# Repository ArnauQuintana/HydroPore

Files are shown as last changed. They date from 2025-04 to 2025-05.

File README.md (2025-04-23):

# HydroPore
This project was realized in 2022 as my BSc thesis. 
The objective was to design and implement an embedded system for the control of a setup which looked like the following image:  

  

Where (1) are LVDT sensors for displacement measure, (2) a load cell for measuring pressure pushed by an actuator, (3) water pressure sensor and last but not least, 4 cameras in each side of the experiment, like this: 



My mission was to control the actuator while getting data from all sensors. I designed and implemented the PCB with all conditioning and required circuits for this application.  
Here is a photo of the final solution:  



## 📁 Project 1 - [HydroPore_FW]

**Description:**  
Implementation of the bare-metal firmware in a MSP430 microcontroller from TI.

**Key Features:**
- All code was developed for a MSP430 from TI. 
- It is not a real-time application, so no time requirements were needed to be met. 
- It receives and sends data with a GUI in Python through UART protocol

**Location:** `/HydroPore_FW/`

---

## 📁 Project 2 - [HydroPore_Cameras]

**Description:**  
This project was intended to control 1 serial camera with Arduino (we had a total of 4 cameras, so 4 arduinos). Its objective was to trigger the camera capture, read the image information and save it in an SD card every time the main uController asked to. 

**Key Features:**
- Received triggers from central control card with normal GPIOs.
- Protocol used for sending image information from Arduino to SD shell was SPI. 

**Location:** `/HydroPore_Cameras/`

---

## 📁 Project 3 - [HydroPore_GUI]

**Description:**  
Simple Python GUI using 'tkinter' for sending commands and receiving data from sensors. 

**Key Features:**
- Serial communication with UART
- It generates a 'RESULTS.txt' file with data from sensors.

**Location:** `/HydroPore_GUI/`

---

## 📁 Project 4 - [PCB_Project_HydroPore]

**Description:**  
This is the PCB where all conditioning circuits and the microcontroller are allocated. 

**Key Features:**
- Supplied by 2 sources, one for the power part (actuator) and one for the conditioning of sensors data. 
- UART communication for exchanging data with GUI in Python. 

**Location:** `/PCB_Project_HydroPore/`

---
## 📌 Additional Notes

- It is important to consider that this was my first 'big' project. It was entirely realized in 6 months, the short experience and short deadline may made me do some parts not as optimal as possible or containing bugs and innacuraccies. 
- Each project includes its own detailed `README.md` file inside its folder.

---

## 📄 License

This repository is licensed under the [MIT License]. Please see the `LICENSE` file for more details.

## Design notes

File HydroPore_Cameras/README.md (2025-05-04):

# HydroPore Cameras

- Cameras looked like:
  


- PCB built to allocate the camera, the arduino and the SD card shield:
  


- Schematic of the PCB:



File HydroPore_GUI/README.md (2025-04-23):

# HydroPore_GUI
The project was developed with Jupyter Notebook.
The GUI was a simple screen with buttons to move around the menus and reach the command needed.

## Main Menu:


## Commands available:


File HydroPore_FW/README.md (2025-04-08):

# HydroPore_FW

ANEXO_6

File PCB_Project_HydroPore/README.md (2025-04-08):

# PCB_Project_HydroPore

  



Top layer:


Bottom Layer:



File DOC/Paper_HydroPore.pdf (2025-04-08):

# Design and implementation of ‘HydroPore’ Electronic System

Arnau Quintana Llorens
Electronics Telecommunication Engineering University of Barcelona, UB Barcelona, Spain

Abstract—This document summarizes a Final Grade’s Project whose objective is to develop all the electronics that will control an experimental setup. This project includes PCB design, coding and development of a user interface.

Keywords—PCB; C Coding; Python; Arduino; Experimental setup; Electronics; LVDT; Load Cell.

I. INTRODUCTION
The experimental setup consists of an extern structure that will support an internal construction. The internal is formed by a base with a rock at the top and, just above, there’s another structure with another rock that fits perfectly with the first one. Above the second structure we can find death weight that will apply a vertically force. The objective is to move 10 mm the lower structure forcing the two rocks to rub each other. Before the start of the movement, the system will be saturated of water and during the experiment we need to measure:
- Horizontal displacement of the lower structure.
- Vertical displacement of the higher structure.
- Water pressure difference.
- Water removed from the system thought the holes on the 4 laterals.
- Applied force vertically with death weight.
- Applied force horizontally to move the base.

Our objectives can be divided into 4 subobjectives:

1. Study the problem and propose a solution to the manager.
2. Design and implementation of the PCB that will control the system.
3. Develop the software that will manage the PCB.
4. Develop an interface to make the control of the system user friendly.

II. MATERIALS AND METHODS

A. Materials
- LVDT [1]: to measure vertical and horizontal displacement. They are located in position marked with number 1 on Fig 1.
- Load cell [2]: to measure vertical and horizontal applied force. They are located in position marked with number 2 on Fig 1.
- Water pressure sensor [3]: to measure changes of pressure between movements. It is located in position marked with letter ‘Q’ on Fig 1.
- Ultrasonic sensor [4]: to have a security limit of the movement. Will be located at the end of the movement range of the structure.
- Serial cameras [5]: to know how much water has been removed from the system. Will be one of them on every side of the structure.
- Actuator [6]: to move the structure. It is located in position marked with ‘σT’ on Fig 1.

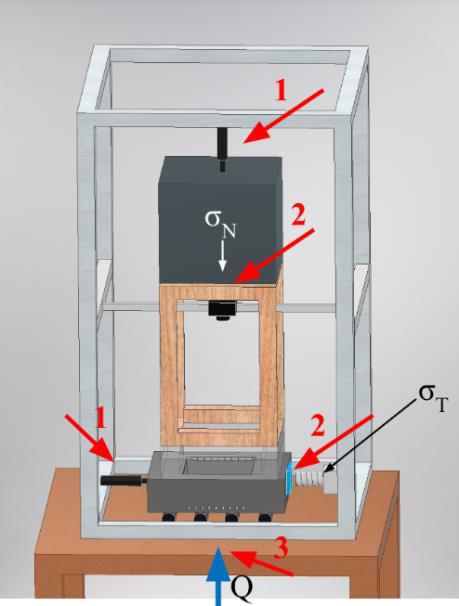
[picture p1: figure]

Fig 1. ‘HydroPore’ experimental setup.

B. Methods
We have divided the design of the system in 4 layers:
- Physical layer: includes all the transducers and the mechanicals.
- Electronics layer includes the PCB and all the components.
- Control layer: includes the software of the microcontroller and the Arduino.
- User layer: includes the methods that the user has to interact with the system.

A layer design helps us to correct the course of any decision during the development of the project without changing a lot of aspects. Physical and electronics layer are palpable; control and user layers are logic.

We have designed the system going from the physical layer to user layer.

III. RESULTS
The initial propose to the head of the project has been approved and developed.

Hardware designed meets the expectations. It is capable of collect all transducers data, process it and export to a PC via UART.

PCB is designed according to EN 55011:2016 norm about electromagnetic emissions on a scientific equipment. In Fig 2 we can see the results.

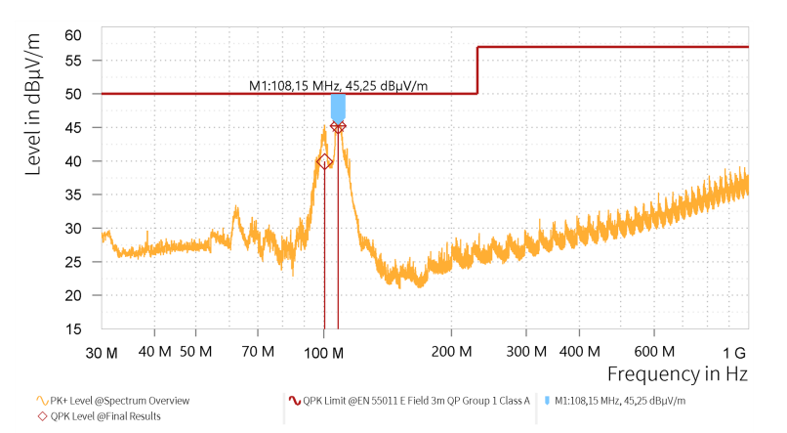
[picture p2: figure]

Fig 2. Results of radiated emissions according to EN-55011.
The software can monitor all the system and detect errors.

User interface can send commands to interact with the system and get data from it with a user-friendly format.

IV. DISCUSSION
After all the explanations of the heads of the project, we traced a solution to meet the requirements.

The PCB is a four-layer design, all of them dedicated to signals. The equipment is placed in a methacrylate cage, to avoid having current circulating through a metal case.

We have tested radiated emissions in a semi-anechoic chamber as we see in Fig 3.

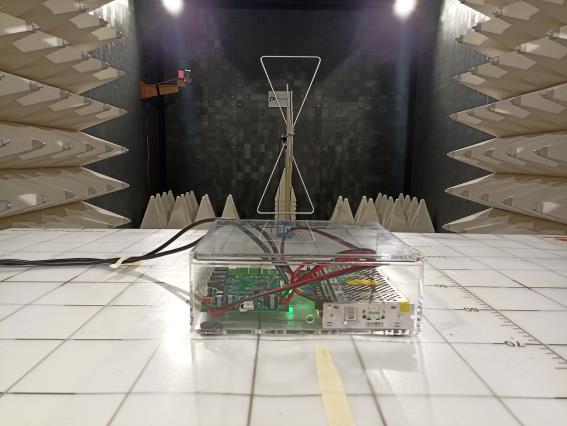
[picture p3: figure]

Fig 3. EUT in the semi-anechoic chamber.

Developed software can control all the electronics and can collect of transducers data, process it and send it to PC via UART.

The user interface is based on an application that have different buttons assigned to all commands that we can send to PCB, as we see in Fig 4.

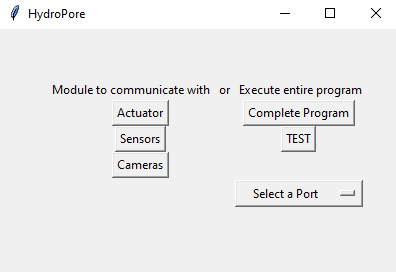
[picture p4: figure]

Fig 4. Main window of the user interface.

REFERENCES

[1] TE Connectivity. (2017, Jul.). DC-SE Series, General Purpose DC LVDT
[Online]. | | | | Available | | on:
https://www.te.com/commerce/DocumentDelivery/DDEController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
[2] HBM. (2021, Jan. 26). S2M Force Transducer Datasheet [Online].
Available | | | | | | on:
https://www.hbm.com/fileadmin/mediapool/hbmdoc/technical/B03594.p df
[3] Sensata Technologies. (2021. Jun. 18). IPS Series Industrial Pressure
Transducer | [Online]. | Available | on: | https://docs.rs-
online.com/165e/A700000008782550.pdf
[4] Kitronik. (2021, Jan. 28). Ultrasoni Ranging Module HC-SR04 [Online]. Disponible en: https://docs.rs-online.com/8bc5/A700000007388293.pdf
[5] Adafruit Industries. (2016, Jun.12). PTC06 Serial Camera Specification
[Online]. | | | Available | on: | | https://docs.rs-
online.com/bb24/0900766b81533f88.pdf
[6] Actuonix Motion Devices Inc. (2016, Sept). Miniature Linear Motion
Series | · | P16 | [Online]. | Available | on: | https://docs.rs-
online.com/1cf0/0900766b81682dc9.pdf

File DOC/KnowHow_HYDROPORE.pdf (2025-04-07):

Versión 0

‘Know How’ del montaje experimental ‘HydroPore’

# ‘KNOW HOW’ DEL MONTAJE EXPERIMENTAL ‘HYDROPORE’

Autor: Arnau Quintana Llorens

El presente documento pretende explicar el funcionamiento de cada una de las partes del sistema, tanto a nivel de circuito, el código y los sensores.

## CONTROL DE CAMBIOS

Autor | Apartado | Fecha | Versión
Arnau Quintana | TODOS | 18-09-2022 | 0

## ÍNDICE

## PCB

En este apartado se puede encontrar la explicación de todos los circuitos que forman el PCB.

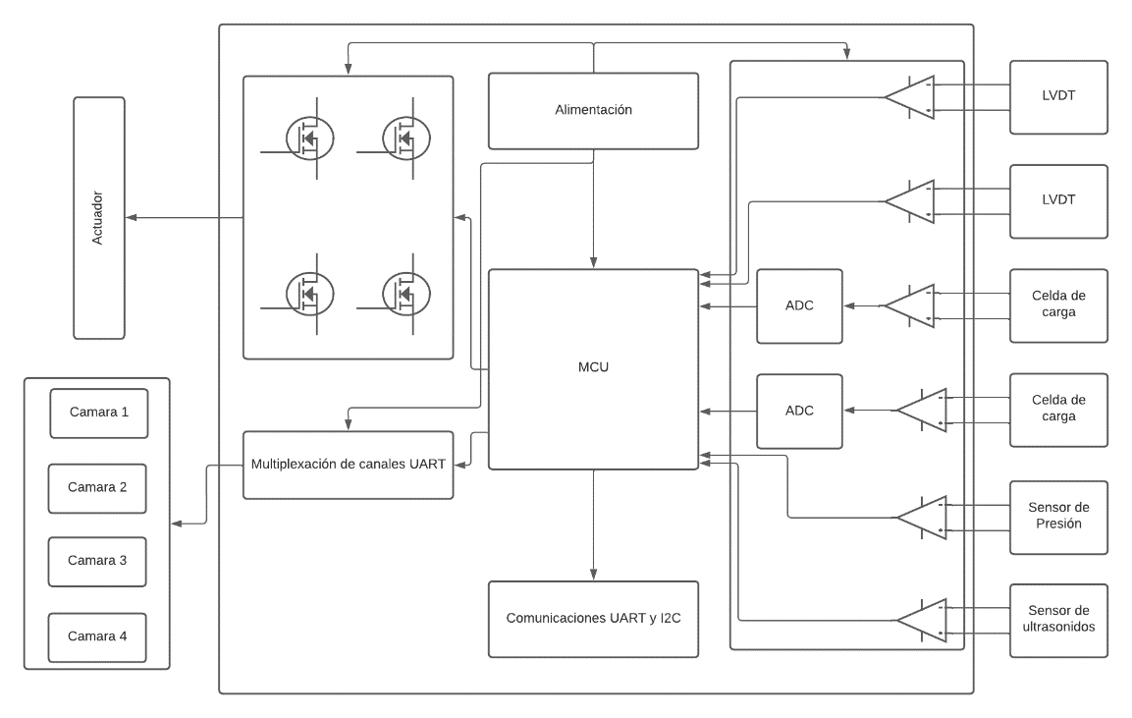
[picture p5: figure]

LOAD CELLS
Las celdas elegidas para el proyecto disponen de 6 cables: Data+, Data-, Alimentación+, Alimentación-, Sensado de alimentación + y sensado de alimentación -.

El circuito para poder recoger datos de las celdas se compone básicamente de 2 partes: un amplificador de instrumentación y un ADC de 14 bits.

El amplificador de instrumentación nos ayuda a amplificar la señal y rechazar el modo común, que en este contexto es muy crítico al trabajar con señales tan pequeñas. Usamos un ADC externo porque el microcontrolador dispone de uno interno de 12 bits, el cual se no queda un poco corto para las señales que medimos de este sensor.

El amplificador tiene una ganancia fija de 160, es decir, la señal que entra saldrá amplificada 160 veces. El ADC dispone de 14 bits, es decir, de hasta 16384 valores digitales. Como lo alimentamos a 5V significa que por cada voltio disponemos de 3276 valores aproximadamente. Esto significa que 1V a la entrada del ADC, se traduce en un valor digital de 3276 a la salida. El cambio es lineal, es decir, siempre que añadamos peso, la salida cambiará de manera proporcional.

Nuestro rango medible es de 0N a 300N. Si quisiéramos aumentarlo, por ejemplo, hasta 600N, deberíamos, como mínimo, cambiar el amplificador y poner uno de ganancia fija menor; existe un modelo igual que en lugar de 160 de ganancia, tiene 80 (AD8293G80ARJZ-R7). El amplificador se alimenta a 5V, si intentamos sacar más de esa tensión, el componente se satura y a su salida veremos 5V por mucho que aumentemos por encima de 300N la fuerza aplicada en la celda.

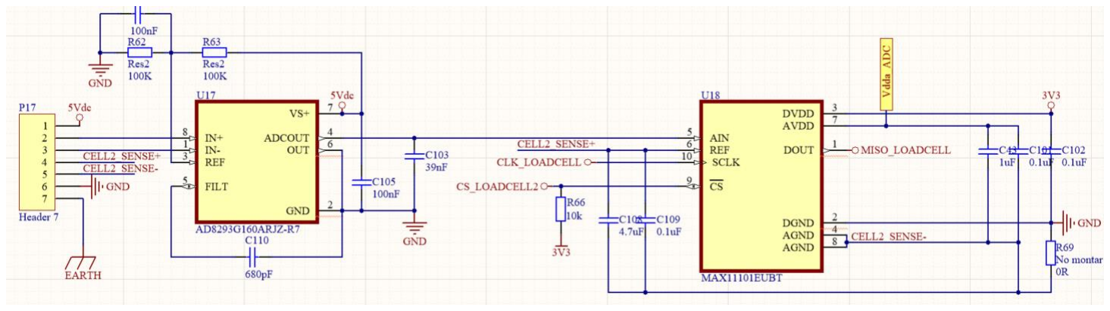
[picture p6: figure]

LVDTs
Este sensor dispone de 4 líneas: +15Vdc, GND, Datos+ y Datos-. Nos devuelve una señal de 0V a 5V dependiendo de la extensión del núcleo. Nuestro sensor es 3.3V tolerante, por lo que aparte de acondicionar la señal analógica debemos reducir su amplitud. Para ello usamos un amplificador diferencial, que básicamente es un amplificador operacional con una cierta topología capaz de amplificar la diferencia entre sus entradas. Si en la entrada positiva tenemos 6V y en la otra 1V, la salida será de 5V, siempre y cuando no la amplifiquemos jugando con el valor de las resistencias. Nosotros hemos dimensionado el circuito teniendo en cuenta que la señal máxima que nos puede devolver el LVDT es de 6V (haciendo pruebas en el laboratorio vimos que esa era la tolerancia), por lo que cuando el LVDT devuelva 6V, el microcontrolador recibirá 3.3V.

Vo = (

R65
R83

) · (VPIN2 − VPIN3)

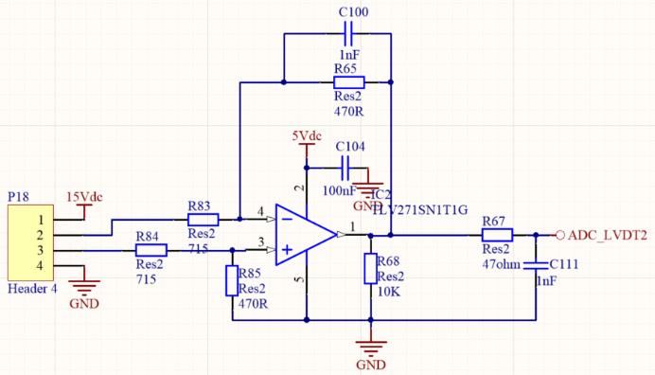
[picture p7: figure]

SENSOR DE PRESIÓN
Este sensor es muy parecido en cuanto a funcionamiento al LVDT. Se alimenta a 15V y nos devuelve una señal de 0V a 5V dependiendo de la presión leída. Usamos el mismo circuito que en los LVDT para acondicionar la señal.

ULTRASONIDOS
Lo único que hemos tenido que añadir ha sido un pequeño divisor resistivo, ya que el sensor nos devuelve una señal digital de 0V a 5V, mientras que nuestro microcontrolador soporta de 0V a 3.3V. Este sensor sólo tiene parte digital, por lo que no hemos tenido que acondicionar nada.

CÁMARAS
En el PCB tenemos un circuito dedicado a la comunicación con las cámaras, pero parte de él no lo usamos por cuestiones de eficiencia. Lo compone 2 partes: un multiplexor digital y un driver RS232. El primero nos permite usar 2 canales UART para transformarlos en 4, tal como muestra la siguiente imagen:

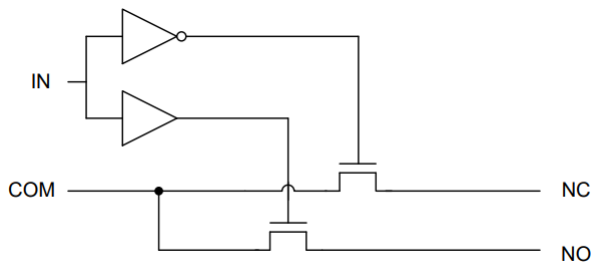
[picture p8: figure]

IN es el selector de canal, COM es la señal que queremos multiplexar, NC y NO son las dos salidas. Es un circuito bidireccional, por lo que podemos ir de COM a NC o NO, o podemos ir de NC o NO a COM; esto nos permite tanto enviar datos como recibirlos a través de la misma línea.

El driver RS232 nos ayuda a pasar la señal de niveles UART a niveles RS232, el cual es más seguro para comunicaciones en las que haya cierta distancia.

Los puentes de la parte inferior de la imagen son los que usamos en nuestro circuito final, ya que sirven para poder saltar el driver RS232.

En el montaje final únicamente se usa el multiplexor digital y los puentes para saltar el driver RS232 como comentamos. Esto es así porque no nos comunicamos a través de UART con las cámaras ya que cada una de ellas tiene un Arduino dedicado. Las líneas que van a las cámaras son la de ‘trigger’ y la de ‘acknowledge’ del ‘trigger’.

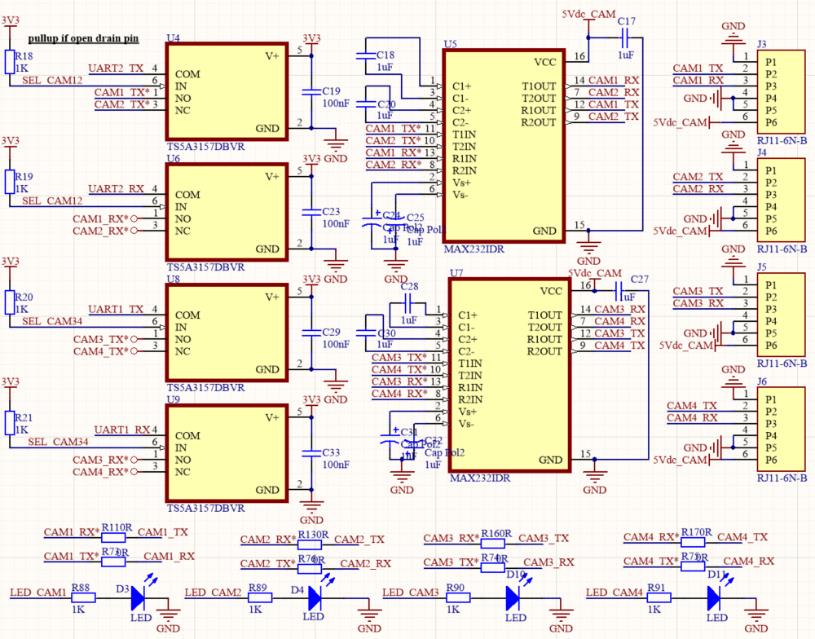
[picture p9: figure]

La solución final para tomar las imágenes con las cámaras es la siguiente:

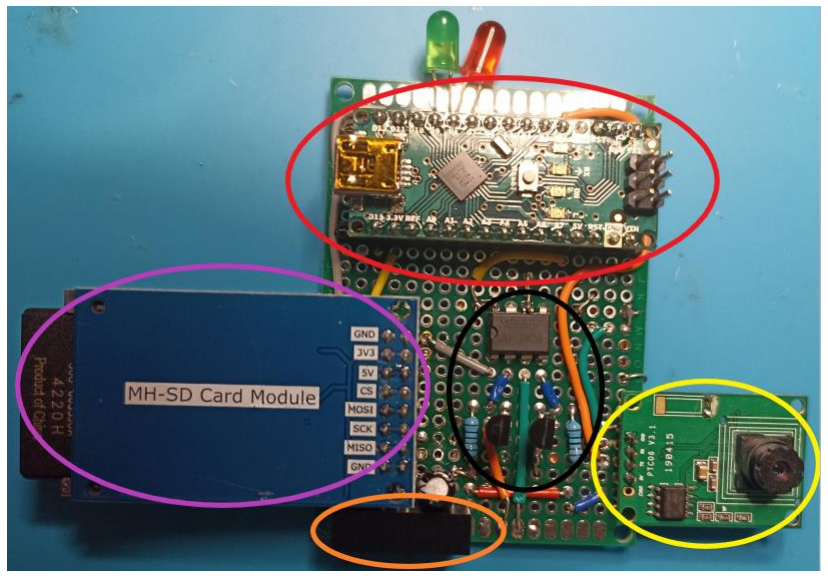
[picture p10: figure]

COLOR | PARTE DEL SISTEMA
| Arduino
| Circuito ‘toggle’ ON/OFF
| ‘Shield’ tarjeta SD
| Convertidor DCDC aislado 15V a 5V
| Cámara serie

Alimentamos el módulo con el convertidor DCDC MPF1505S-1W, que le entran 15V desde la PCB principal a través del cable y los reduce a 5V, que es la tensión con la que funciona todos los componentes del módulo.

En esta PCB se sitúa: el ‘SHIELD’ donde se conecta la tarjeta SD en la que guardaremos las imágenes, la cámara que toma las imágenes, el Arduino que controla la faena, un convertidor que alimenta toda la placa y un pequeño circuito para detectar el ‘trigger’ que nos envía el microcontrolador principal para saber cuándo debemos empezar o parar de tomar imágenes, ya que una vez empezamos, cada 20 segundos aproximadamente se tomará una imagen.

Existe una cuestión muy importante a tener en cuenta en este circuito: la referencia de la parte del Arduino y la referencia del microcontrolador principal no son la misma, ya que usamos un DCDC aislado para alimentar todo el módulo. Debemos separar el ‘trigger’ que enviamos desde el microcontrolador principal al Arduino y la señal de ‘trigger correcto’ que envía el Arduino al microcontrolador principal. Para esta misión hemos usado optoacopladores, son dispositivos dedicados específicamente a lo que necesitamos.

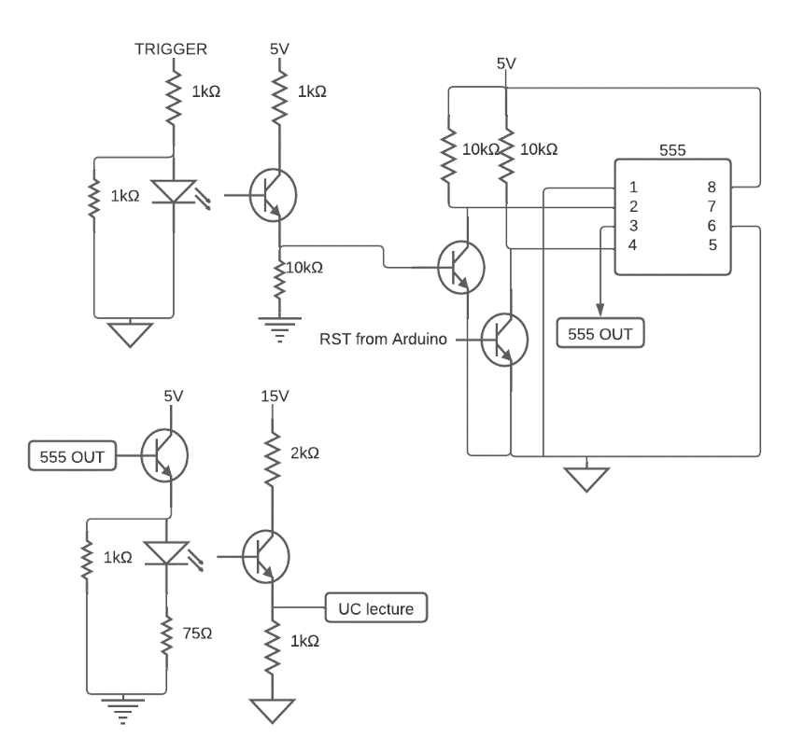
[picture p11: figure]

Las siguientes tablas resumen las conexiones entre la cámara, la tarjeta SD y el Arduino:

Pin Arduino | Pin adaptador tarjeta SD
GND | GND
3.3V | 3V3*
5V | 5V*
D10 | CS
D11 | MOSI
D13 | SCK
D12 | MISO
GND | GND
*Si conectamos 5V, no conectamos 3V3. Si conectamos 3V3, no conectamos 5V.
Pin Arduino | Pin Cámara
GND | GND
D3 | RX (divisor resistivo 5V a 3V3)
D2 | TX
5V | 5V
Pin Arduino | Circuito 555
D5 | 555 OUT
D6 | RST from Arduino
Cable RJ11 | Módulo Cámaras
Cable rojo | TRIGGER
Cable negro | UC lecture
Cable blanco | 15V
Cable gris | GND

ACTUADOR

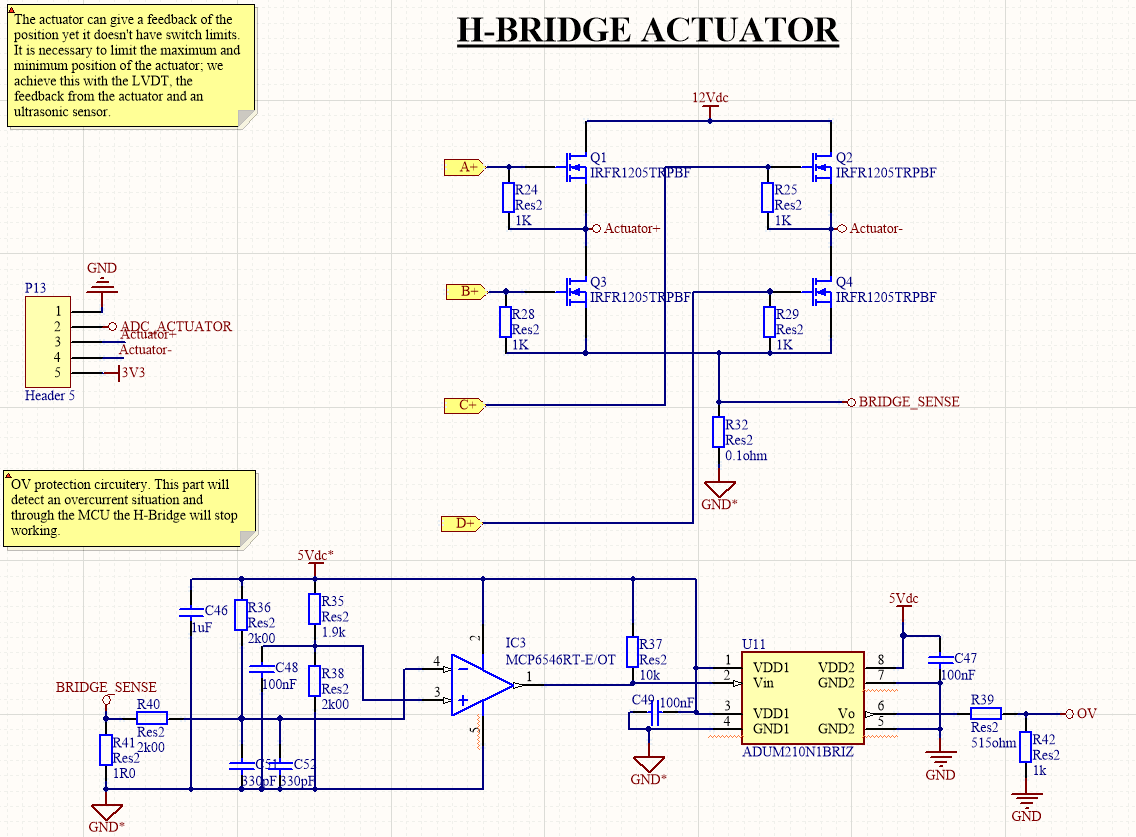
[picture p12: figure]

En esta primera imagen vemos el puente H con el circuito detector de sobre corriente. El actuador se moverá hacia adelante o hacia atrás dependiendo de cómo lo polaricemos. La manera más sencilla y efectiva de usar esa capacidad es con un puente en H, si cerramos los transistores en diagonal haremos fluir la corriente a través de la carga, que es el actuador, en la dirección que nos interese.

Por otro lado, tenemos el circuito de la parte inferior de la imagen. Mediante una SHUNT (una resistencia de baja impedancia y tolerancia) sensaremos la corriente que atraviesa el puente para poder proteger a los transistores de un cortocircuito o de un consumo excesivo. Se basa en la ley de ohm, por ejemplo, si la corriente que atraviesa la SHUNT es de 1A y la resistencia de es 1mOhm, la señal ‘BridgeSense’ será de 1mV (V = I · R). Lo que hacemos con esa señal es llevarla directamente a la entrada negativa de un comparador. En la entrada positiva tenemos un nivel de continua constante. Si la señal de la SHUNT no supera esa señal de continua, todo va bien, la salida será 1 y no tendremos que hacer nada. En cuando la salida sea 0, deberemos actuar para parar el movimiento del actuador, ya que algo no está funcionando como debería.

En la segunda imagen, que encontramos más abajo, tenemos los drivers de los transistores. Estos se dedican a adaptar la señal del microcontrolador a una que sea correcta para la puerta de los MOS, ya que son muy delicados. Además, esos drivers son aislados, lo que significa que la referencia de la parte izquierda y la de la derecha no son iguales. Alimentamos el puente H con la fuente de 12V y el microcontrolador se alimenta indirectamente de la fuente de 15V, sus referencias son distintas y hemos de tenerlo en cuenta. Los componentes que rodean al driver son: un filtro RC en la entrada (para eliminar componentes de alta frecuencia de la señal), capacidades de desacoplo en ambos lados del driver (para mantener estable la tensión de alimentación), una resistencia de puerta (para limitar la corriente que llega a la gate del MOSFET y una resistencia y un diodo de descarga de la puerta (para descargar la carga de la puerta mucho más rápido cuando debamos abrir el transistor).

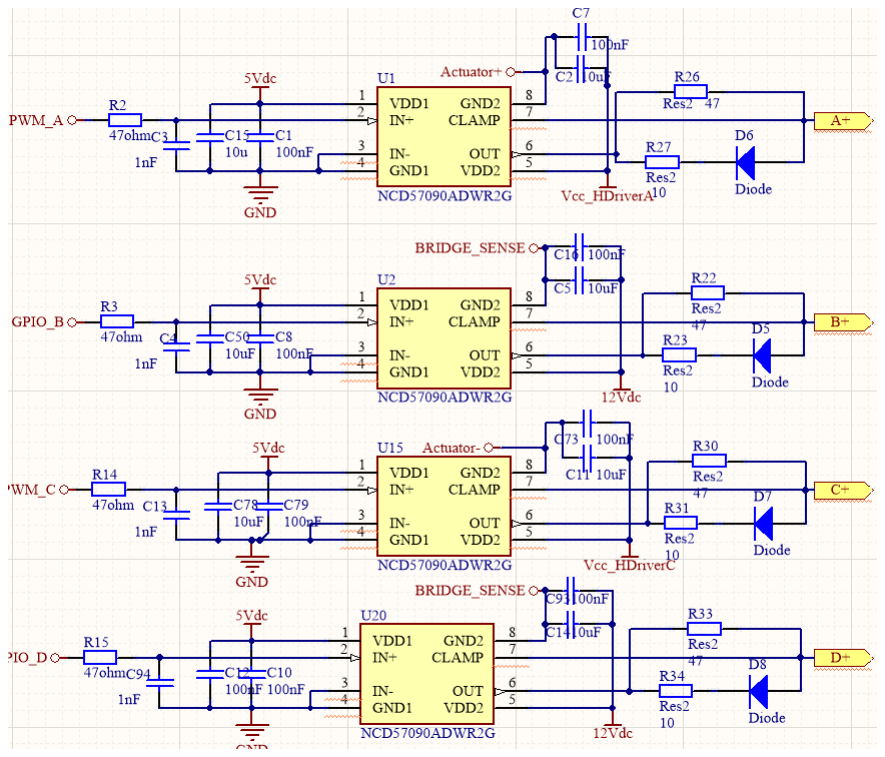
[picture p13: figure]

ALIMENTACIONES
Todas las tensiones que obtienen a partir de 2 fuentes, una de 12V para la parte del puente H, otra de 15V para toda la parte de control y sensores. Para obtener todas las alimentaciones que necesitamos, ya que, por ejemplo, el microcontrolador necesita 3.3V y algunos sensores 5V, usamos LDOs (reguladores lineales). Más abajo tenemos una imagen del circuito, todos son parecidos: condensadores en la entrada y salida para mantener estable la tensión y reducir el rizado.

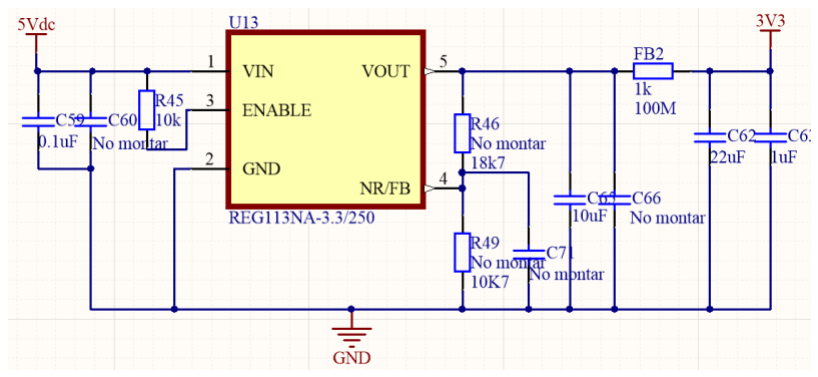
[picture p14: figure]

POSICIÓN DE LOS CIRCUITOS EN EL PCB

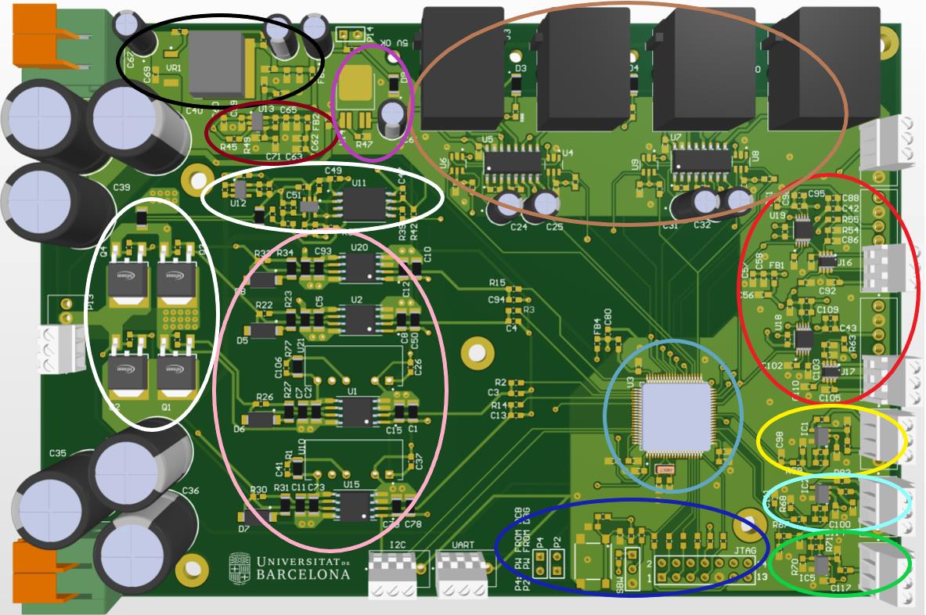
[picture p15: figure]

COLOR | PARTE DEL SISTEMA
| LDO 15Vdc a 5Vdc para sensores, drivers del puente H y uControlador
| LDO 5Vdc a 3.3Vdc para el uControlador
| Regulador lineal de 15Vdc a 5Vdc para Arduinos y cámaras
| Driver a RS232 y multiplexores digitales para las cámaras
| Puente H y circuito de detección de sobre corriente
| Drivers del puente H
| Conector de programación del uControlador
| uControlador
| Acondicionamiento de la señal del sensor de presión
| Acondicionamiento de la señal del LVDT1
| Acondicionamiento de la señal del LVDT2
| Acondicionamiento de la señal de las celdas de carga

ERRORES EN PCB
Este apartado pretende resumir los errores de diseño que se han cometido y que deberían corregirse de cara a una versión B de la PCB.
- Referencia de los convertidores de los drivers del ‘high side’ del puente H.

La referencia del secundario del convertidor que alimenta el driver del transistor ‘A’ debe ir conectada a la ‘net’ ‘Actuator+’, puesto que es esta la que está conectada al ‘source’ del transistor.

La referencia del secundario del convertidor que alimenta el driver del transistor ‘C’, debe ir conectada a la ‘net’ ‘Actuator-‘, puesto que es esta la que va conectada al ‘source’ del transistor.

Para arreglar este problema en la versión A del PCB, se ha cortado la pista que une GND con la referencia de la parte del secundario del convertidor y se ha unido la referencia del convertidor a donde corresponde con un cable.

- Pin ‘OUT’ del amplificador de instrumentación cortocircuitado con GND.

Al realizar el esquema y pasar una línea por encima de la otra, el pin ‘OUT’ se cortocircuitó con la GND. El pin ‘OUT’ debe ir conectado al condensador que tiene el otro pin conectado a ‘FILT’. En caso de duda, en el datasheet del componente aparece un esquema de cómo debe ir conectado el amplificador.

Para corregir el error en la versión A del PCB, se ha levantado el pin ‘OUT’ del driver para que no toque con el pad y se ha levantado el condensador que debe unir ‘OUT’ y ‘FILT’ para que tampoco toque con GND. Mediante un cable se ha unido el pin del driver con el condensador.

- LDO de la alimentación de las cámaras y Arduino no usado.

La primera idea del proyecto para la parte de las cámaras es que se comunicaran con el microcontrolador principal, por lo que únicamente deberíamos hacer llegar los 5V a las cámaras. Conforme avanzaba el proyecto y nos dimos cuenta de lo poco eficiente que era ese método, ingeniamos un módulo para poder resolver el problema, pero ese módulo consumía mucho más que la cámara sola. Al realizar las pruebas funciones del PCB nos dimos cuenta de que usar un LDO para alimentar los 4 módulos no era viable, ya que el consumo de cada uno de ellos es de aproximadamente 1.5W, lo que hacía calentarse en exceso al regulador.

Para solucionar el problema en la versión A de circuito hemos cortocircuitado los 5V de las cámaras con los 15V de la fuente, es decir, hemos quitado todos los componentes de la parte de alimentación de las cámaras y hemos cortocircuitado la entrada y la salida del regulador. Esto hace que la línea 5Vdc_CAM, sea en realidad, 15V. Esos 15V luego los pasamos a 5V en cada módulo con un convertidor DCDC (podemos revisar la explicación de cómo funciona el módulo un poco más arriba, en este mismo documento).

- Serigrafia en PCB y pines del ultrasonidos.

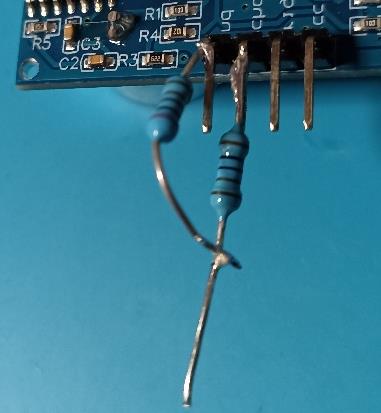
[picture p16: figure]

En la capa bottom del PCB tenemos el nombre de cada pin para poderlos identificar. Por motivos de software, los pines ECHO y TRIGGER están girados, es decir, donde en la placa pone ‘trigger’ conectamos el ‘echo’ y donde pone ‘echo’ conectamos el ‘tigger’.

Además, hemos incorporado un divisor de tensión en el pin ‘ECHO’ del ultrasonidos tal como vemos en la imagen. Esa señal es de 5V mientras que el micro permite 3.3V.

## CÓDIGO EN C

Usamos un MSP430 de Texas Instruments, concretamente el MSP430FR6043. Para programarlo, usamos el Code Composer Studio, la versión 10.4.0. El programador es el MSP-FET430UIF V1.

Tenemos el código separado por archivos intentando tener en cada uno funciones relacionadas entre sí.

Main.c | Archivo principal. El micro ejecuta la función ‘main’ situada en este archivo.
ADC.c | Funciones relacionadas con el ADC, desde configuración hasta recogida de datos.
ADC.h | Header del ADC.c. Encontramos las funciones que usamos en otra parte del código.
Control.c | Funciones principales, en este archivo usamos todas las librerías.
Control.h | Header del Control.c.
COMs.c | Funciones relacionadas con las comunicaciones UART y SPI.
COMs.h | Header de las funciones del archivo COM.c.
Clocks.c | Contiene la función de inicialización de los relojes.
Clocks.h | Header de la función de inicialización de los relojes.
DrivingH.c | Funciones relacionadas con el ultrasonidos y el movimiento del actuador.
DrivingH.h | Header con las funciones del archivo DrivingH.c.

En el código se han dejado comentada una parte del código, es decir, en la última ‘release’ del código no se incluye, su función es la siguiente: si el microcontrolador detecta medidas muy bajas en el LVDT (rondando los 0.01mm) que lo dé como error y no mueva el actuador, es decir, es una protección que no permitiría si quiera mover el motor sin el LVDT conectado. Se ha dejado sin usar porque puede darse el caso que el LVDT realmente mida 0.01mm y nos devuelva un error cuando no sería cierto.

Actualmente lo que pasaría que es el que el actuador se movería aunque el LVDT no estuviera conectado, pero cuando el microcontrolador detectara que las medidas del LVDT no varían, se pararía y nos devolvería un error. Si queremos usar esa protección simplemente habría que descomentar esa parte y reprogramar el microcontrolador.

## CÓDIGO EN PYTHON

La aplicación tiene la misión de enviar comandos al microcontrolador, recibir los datos de los sensores y grabarlos en un documento de texto.

Usamos Jupyter Notebook como IDE para programar en Python. Hemos usado la versión Python3. Recomiendo instalar el Anaconda Navigator para poder trabajar cómodamente.

El código está organizado de la siguiente manera:

1. Función para cada botón.
2. Funciones de envío y recogida de datos.
3. Inicializaciones.

Usamos diversas librerías para poder comunicarnos y realizar las tareas:

1. Pyserial: para enviar y recibir comandos UART.
2. Time: para poder realizar timestamps de las medidas recibidas.

Para instalarlas deberemos abrir el ‘Anaconda Prompt’ (parecido al cmd de Windows, básicamente un intérprete de comandos) y escribir: ‘pip install xxx’, donde xxx es la librería por instalar.

## CÓDIGO EN ARDUINO

Debemos comentar que Arduino está trabajando a las velocidades que recomienda el fabricante, si necesitamos más velocidad en la toma de imágenes podríamos intentar subir la velocidad de reloj de la comunicación SPI con la tarjeta SD y/o incrementar el baudrate de la comunicación serie con las cámaras.

Pasando a comentar el código, lo primero que hacemos es inicializar todos los recursos que usaremos, desde los puertos digitales a los módulos de comunicaciones. Durante todo el programa usamos las librerías que nos proporciona el fabricante, por lo que veremos funciones que no están definidas en nuestro ‘main’.

El programa inicia comprobando que tengamos la tarjeta SD y la cámara conectada, de no ser así, el LED rojo parpadeará indefinidamente y dejamos el programa colgado.

Para poder volver a comprobar que está todo conectado, deberemos reiniciar el Arduino y que inicie el programa de nuevo. Si la comprobación ha sido correcta, entraremos en un bucle de espera en que estaremos alerta de un trigger enviado desde el microcontrolador principal. Lo sabremos porque el LED verde estará encendido mientras en rojo permanece apagado. Cuando se reciba el trigger, el LED rojo se encenderá y se apagará el verde, indicando que el sistema está ocupado.

En este momento tomaremos la imagen y se guardará en la tarjeta SD, debemos tener en cuenta que es una cámara serial, es decir, envía la información de la imagen por UART, lo que conlleva que el proceso demore unos segundos por imagen. Una vez Arduino la tenga, debe guardarla en la SD a través de SPI, que es un protocolo más rápido que el serie, pero a su vez que requiere de cierto tiempo. Una vez finalice el proceso (en unos 25 segundo por imagen), el LED verde se encenderá por un segundo y medio mientras el rojo está apagado.

Si no recibimos otro trigger, no entraremos en el modo espera y pasaremos directamente a tomar otra imagen.

Al final de cada secuencia se guarda el tiempo que ha pasado desde que Arduino ha arrancado hasta que se ha guardado la imagen en la SD, para poder tener una referencia del tiempo transcurrido y poder relacionarlo con los datos de los sensores.

## SENSORES

En este apartado encontramos la explicación del funcionamiento de los sensores escogidos para el proyecto a nivel teórico.

LVDT
Usamos el modelo DC-SE 0-12.5MM de TE Connectivity.

La salida depende directamente de la extensión del núcleo: más dentro del cuerpo del sensor, mayor salida tendremos. En concreto para nuestro modelo, habrá una variación de 0.394V por milímetro. Esto no significa que la resolución sea esa, es una referencia que nos da el fabricante para poder hacer los correspondientes cálculos ya que el cambio en la salida entre movimientos es lineal.

El sensor permite alimentarse desde 8.5V a 28V, en nuestro diseño disponemos de 15V, y como está en el rango permitido, es la tensión que usamos.

SENSOR DE PRESIÓN DEL AGUA
Usamos el modelo 797-5037 de RS PRO, aunque es muy posible que cambie en un futuro.

El funcionamiento es muy parecido al del LVDT, pero en este caso debemos sacar nuestra conclusión con respecto a la variación de la salida. En este caso, el rango de la salida es de 0 a 5V, y el sensor mide hasta 10 bares, lo que significa que, cuando este midiendo 10 bares, la salida es de 5V. Con esta referencia podemos hacer los cálculos pertinentes para todas las demás medidas.

El sensor permite alimentarse desde 9V a 32V, en nuestro diseño disponemos de 15V, y como está en el rango permitido, es la tensión que usamos.

LOAD CELLS
La celda que usamos en el proyecto es la S2M de HBM, en concreto el modelo de 200N.

Las celdas de carga tienen una salida del tipo 2mV/V, es decir, cuando estén midiendo su carga nominal (en nuestro caso 200N), la salida será de 2mV por cada voltio aplicado de alimentación. Si nosotros alimentamos la celda con 5V, la salida será de 10mV cuando carguemos un peso de 200N.

Para saber mejor la salida teórica del sensor, hemos de seguir la siguiente fórmula:

U = U0 ∗ C ∗

F

Fnom

U = salida en V, U0 = alimentación (5V en nuestro caso), C = tipo de salida (nuestro caso 2mV/V), F = carga que aplicamos y Fnom = carga nominal de la celda (en nuestro caso 200N).

El circuito de la PCB está dimensionado para medir hasta 300N (en las especificaciones del proyecto se pidió medir hasta 200N, pero siempre es conveniente dejar un margen). Cuando en este contexto decimos ‘dimensionar’ nos referimos a nivel de componentes; en el apartado de la PCB podemos ver en detalle cómo funciona el circuito.

Cuando la celda mide 0N, en la salida del amplificador tendremos 2.5V. Esto es debido al funcionamiento de la propia celda, ya que se basa en un puente de Wheatstone. Esto se ha tenido en cuenta en el código Python, al convertir el valor digital a analógico.

El sensor permite alimentarse desde 0.5V a 12V, pero en nuestro diseño disponemos de 5V, y como está en el rango permitido, es la tensión que usamos.

CÁMARAS
Para poder controlar las cámaras hemos optado por dedicar un Arduino Nano a cada una de ellas. Son de tipo serie, por lo que necesitamos únicamente dos cables para obtener la información de ellas (RX y TX). Si no lo hiciéramos así, sólo podríamos tomar una imagen (ya que no podríamos hacer otra tarea en paralelo), y tardaríamos aproximadamente 2 minutos en hacer todo el proceso (tomar la foto, recibir los ‘arrays’ de datos y enviarlos al ordenador).

Con los Arduino tenemos la posibilidad de, independientemente de lo que haga el sistema, ir tomando imágenes y guardarlas en una tarjeta SD.

La cámara, la tarjeta SD y el Arduino van conectados entre sí, pero aparte tenemos un pequeño circuito en el centro que es necesario explicar. Básicamente es un circuito para mantener el ‘trigger’ que nos envía el microcontrolador principal hasta que el Arduino pueda leerlo. Imaginemos que el microcontrolador nos envía un ‘trigger’ pero el Arduino no está preparado para leerlo ya que está acabando de grabar una imagen en la SD; el microcontrolador sólo mantendrá el trigger durante unos milisegundos ya que debe hacer otras tareas. Podríamos llegar a perder el ’trigger’. Hemos montado un pequeño circuito ON/OFF controlado por 2 señales: SET y RESET.

El funcionamiento es el siguiente:

El pin ‘SET’ del BJT va conectado el microcontrolador, es el ‘trigger’ que recibiremos; se encarga de poner ‘OUT’ a 1. El pin RST del BJT va conectado al Arduino, una vez hayamos leído el ‘trigger’ deberemos volver a poner el ‘OUT’ a 0 a la espera de otro ‘trigger’.

El microcontrolador principal envía el ‘trigger’ y debe leer el ‘OUT’ para ver si se pone a 1, si es así, lo da por bueno y sigue con otras tareas. Cuando el Arduino lea un 1 en el ‘OUT’, ejecutará un ‘trigger’ que implica empezar a tomar fotos o parar según lo que esté haciendo en ese momento y volverá a poner el ‘OUT’ a 0 a la espera del siguiente ‘trigger’ desde el microcontrolador.

Tanto el Arduino como el ‘SHIELD’ de la tarjeta SD se pueden extraer, no van soldados a la placa. Si lo hacemos, es muy importante volver a conectarlo como estaba, no funcionará de no hacerlo así. Es muy importante que todo esté conectado correctamente cuando conectamos la alimentación.

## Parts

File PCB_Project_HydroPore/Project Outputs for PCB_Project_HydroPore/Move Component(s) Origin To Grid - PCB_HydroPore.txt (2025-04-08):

Move Component(s) Origin to Grid
Filename     : C:\Users\Public\Documents\Altium\Projects\PCB_Project_HydroPore\PCB_HydroPore.PcbDoc
Date         : 13/04/2022
Time         : 21:13:20
Time Elapsed : 00:00:01

    SOIC Component U20-NCD57090ADWR2G (3497.933mil,3129.921mil) on Top Layer - Component pads are OFF grid. No action taken.
    SOIC Component U15-NCD57090ADWR2G (3497.933mil,3393.701mil) on Top Layer - Component pads are OFF grid. No action taken.
    SOIC Component U2-NCD57090ADWR2G (3500mil,2614.173mil) on Top Layer - Component origin is already ON grid. - Component pads are OFF grid. No action taken.
    SOIC Component U1-NCD57090ADWR2G (3498.228mil,2884.843mil) on Top Layer - Component pads are OFF grid. No action taken.
    SMT Small Component C94-Cap (4275.591mil,2618.11mil) on Top Layer - Component pads are OFF grid. No action taken.
    SMT Small Component C93-Cap (3116.043mil,3027.559mil) on Top Layer - Component pads are OFF grid. No action taken.
    SMT Small Component C79-Cap (3783.135mil,3295.279mil) on Top Layer - Component pads are OFF grid. No action taken.
    SMT Small Component C78-Cap (3877.953mil,3295.276mil) on Top Layer - Component origin is already ON grid.
    SMT Small Component C73-Cap (3116.043mil,3295.276mil) on Top Layer - Component pads are OFF grid. No action taken.
    SMT Small Component C50-Cap (3787.402mil,2519.685mil) on Top Layer - Component origin is already ON grid.
    SMT Small Component R91-Res2 (6740.158mil,4401.575mil) on Top Layer - Component origin is already ON grid. - Component pads are OFF grid. No action taken.
    SMT Small Component R90-Res2 (5933.071mil,4377.953mil) on Top Layer - Component origin is already ON grid. - Component pads are OFF grid. No action taken.
    SMT Small Component R89-Res2 (5125.984mil,4377.953mil) on Top Layer - Component origin is already ON grid. - Component pads are OFF grid. No action taken.
    SMT Small Component R88-Res2 (4311.024mil,4381.89mil) on Top Layer - Component origin is already ON grid. - Component pads are OFF grid. No action taken.
    SMT Small Component D11-LED (6736.221mil,4570.866mil) on Top Layer - Component origin is already ON grid.
    SMT Small Component D10-LED (5933.071mil,4570.866mil) on Top Layer - Component origin is already ON grid.
    SMT Small Component R87-Res2 (6545.276mil,2795.276mil) on Top Layer - Component pads are OFF grid. No action taken.
    SMT Small Component R86-Res2 (6578.74mil,2685.039mil) on Top Layer - Origin changed from [6576.772mil:2685.039mil] to [6578.74mil:2685.039mil]
    SMT Small Component R85-Res2 (6543.307mil,3102.362mil) on Top Layer - Component origin is already ON grid. - Component pads are OFF grid. No action taken.
    SMT Small Component R84-Res2 (6578.74mil,3232.284mil) on Top Layer - Component origin is already ON grid. - Component pads are OFF grid. No action taken.
    SMT Small Component R83-Res2 (6578.74mil,3307.087mil) on Top Layer - Component origin is already ON grid. - Component pads are OFF grid. No action taken.
    SMT Small Component R44-Res2 (6437.008mil,3736.22mil) on Top Layer - Origin changed from [6438.976mil:3736.22mil] to [6437.008mil:3736.22mil]
    SMT Small Component Y2-CRYSTAL (4759.842mil,2425.197mil) on Top Layer - Component origin is already ON grid. - Component pads are OFF grid. No action taken.
    SMT Small Component C45-Cap (4661.417mil,2271.653mil) on Top Layer - Component pads are OFF grid. No action taken.
    SMT Small Component C44-Cap (4862.205mil,2271.653mil) on Top Layer - Component pads are OFF grid. No action taken.
    Component J6-RJ11-6N-B (6455.118mil,4299.606mil) on Top Layer - Component pads are OFF grid. No action taken.
    Component J5-RJ11-6N-B (5651.969mil,4295.669mil) on Top Layer - Component pads are OFF grid. No action taken.
    Component J4-RJ11-6N-B (4844.882mil,4295.669mil) on Top Layer - Component pads are OFF grid. No action taken.
    Component J3-RJ11-6N-B (4033.858mil,4299.606mil) on Top Layer - Component pads are OFF grid. No action taken.
    SMT Small Component C43-Cap (6478.347mil,1545.276mil) on Top Layer - Component pads are OFF grid. No action taken.
    SMT Small Component C42-Cap (6452.756mil,2370.079mil) on Top Layer - Component pads are OFF grid. No action taken.
    SMT Small Component R47-1k (3245mil,4210mil) on Top Layer - Component pads are OFF grid. No action taken.
    SMT Small Component Y1-CRYSTAL (5311.024mil,2889.764mil) on Top Layer - Component pads are OFF grid. No action taken.
    SMT Small Component VR1-NCP1117DT50G (2177.716mil,4685mil) on Top Layer - Component pads are OFF grid. No action taken.
    SOIC Component U19-MAX11101EUBT (6299.213mil,2240.157mil) on Top Layer - Component origin is already ON grid. - Component pads are OFF grid. No action taken.
    SOIC Component U18-MAX11101EUBT (6312.992mil,1490.158mil) on Top Layer - Component pads are OFF grid. No action taken.
    SOIC Component U17-AD8293G160ARJZ-R7 (6490.158mil,1265.748mil) on Top Layer - Component pads are OFF grid. No action taken.
    SOIC Component U16-AD8293G160ARJZ-R7 (6464.567mil,2019.685mil) on Top Layer - Component pads are OFF grid. No action taken.
    SMT SIP Component U14-LF50ABPT-TR (3195mil,4486.181mil) on Top Layer - Component pads are OFF grid. No action taken.
    Component U13-REG113NA-3.3/250 (2366.102mil,4316.693mil) on Top Layer - Component pads are OFF grid. No action taken.
    Component U12-LD2981ABM50TR (2324.646mil,1623.386mil) on Top Layer - Component pads are OFF grid. No action taken.
    SOIC Component U11-ADUM210N1BRIZ (3300.354mil,2080.157mil) on Top Layer - Component pads are OFF grid. No action taken.
    SOIC Component U10-MCP6567-E/SN (2814.055mil,2063.032mil) on Top Layer - Component pads are OFF grid. No action taken.
    SOIC Component U9-TS5A3157DBVR (5944.882mil,3767.717mil) on Top Layer - Component pads are OFF grid. No action taken.
    SOIC Component U8-TS5A3157DBVR (5354.331mil,3767.717mil) on Top Layer - Component pads are OFF grid. No action taken.
    SOIC Component U7-MAX232IDR (5657.48mil,4027.559mil) on Top Layer - Component pads are OFF grid. No action taken.
    SOIC Component U6-TS5A3157DBVR (3854.331mil,3787.402mil) on Top Layer - Component origin is already ON grid. - Component pads are OFF grid. No action taken.
    SOIC Component U5-MAX232IDR (4163.583mil,4012.441mil) on Top Layer - Component pads are OFF grid. No action taken.
    SOIC Component U4-TS5A3157DBVR (4488.189mil,3783.465mil) on Top Layer - Component origin is already ON grid. - Component pads are OFF grid. No action taken.
    LCC Component U3-MSP430F6459TPZR (4896.102mil,2875.118mil) on Top Layer - Component pads are OFF grid. No action taken.
    Small Component S1-SW-SPST (5417.638mil,1264.685mil) on Top Layer - Component pads are OFF grid. No action taken.
    SMT Small Component R79-Res2 (6303.15mil,2889.764mil) on Top Layer - Component origin is already ON grid. - Component pads are OFF grid. No action taken.
    SMT Small Component R78-Res2 (6188.976mil,2929.134mil) on Top Layer - Component origin is already ON grid. - Component pads are OFF grid. No action taken.
    SMT Small Component R71-Res2 (6413.386mil,2838.583mil) on Top Layer - Component origin is already ON grid. - Component pads are OFF grid. No action taken.
    SMT Small Component R70-Res2 (6303.15mil,2740.157mil) on Top Layer - Component origin is already ON grid. - Component pads are OFF grid. No action taken.
    SMT Small Component R69-No montar (6214.567mil,1702.756mil) on Top Layer - Component pads are OFF grid. No action taken.
    SMT Small Component R68-Res2 (6228.346mil,3149.606mil) on Top Layer - Component origin is already ON grid. - Component pads are OFF grid. No action taken.
    SMT Small Component R67-Res2 (6275.591mil,3039.37mil) on Top Layer - Origin changed from [6277.559mil:3039.37mil] to [6275.591mil:3039.37mil]
    SMT Small Component R66-10k (6198.819mil,1478.346mil) on Top Layer - Component pads are OFF grid. No action taken.
    SMT Small Component R65-Res2 (6425.197mil,3114.173mil) on Top Layer - Component origin is already ON grid. - Component pads are OFF grid. No action taken.
    SMT Small Component R64-Res2 (6551.181mil,3692.913mil) on Top Layer - Component origin is already ON grid. - Component pads are OFF grid. No action taken.
    SMT Small Component R63-Res2 (6592.52mil,1435.039mil) on Top Layer - Component pads are OFF grid. No action taken.
    SMT Small Component R62-Res2 (6482.283mil,1470.472mil) on Top Layer - Component pads are OFF grid. No action taken.
    SMT Small Component R61-No montar (6173.228mil,2444.882mil) on Top Layer - Component pads are OFF grid. No action taken.
    SMT Small Component R60-Res2 (6271.654mil,3507.874mil) on Top Layer - Component origin is already ON grid. - Component pads are OFF grid. No action taken.
    SMT Small Component R59-Res2 (6291.339mil,3433.071mil) on Top Layer - Component origin is already ON grid. - Component pads are OFF grid. No action taken.
    SMT Small Component R58-10k (6173.228mil,2204.724mil) on Top Layer - Component pads are OFF grid. No action taken.
    SMT Small Component R57-Res2 (6440.945mil,3507.874mil) on Top Layer - Component origin is already ON grid. - Component pads are OFF grid. No action taken.
    SMT Small Component R56-Res2 (6551.181mil,3547.244mil) on Top Layer - Component origin is already ON grid. - Component pads are OFF grid. No action taken.
    SMT Small Component R55-Res2 (6452.756mil,2295.276mil) on Top Layer - Component origin is already ON grid. - Component pads are OFF grid. No action taken.
    SMT Small Component R54-Res2 (6448.819mil,2220.472mil) on Top Layer - Origin changed from [6450.787mil:2220.472mil] to [6448.819mil:2220.472mil]
    SMT Small Component R52-Res2 (5261.181mil,2233.425mil) on Top Layer - Component pads are OFF grid. No action taken.
    SMT Small Component R51-Res2 (3230mil,4815mil) on Top Layer - Component pads are OFF grid. No action taken.
    SMT Small Component R50-Cortocircuitar (1810mil,4660mil) on Top Layer - Component pads are OFF grid. No action taken.
    SMT Small Component R49-No montar (2372.284mil,4209.095mil) on Top Layer - Component pads are OFF grid. No action taken.
    SMT Small Component R48-No montar (2565mil,4883.465mil) on Top Layer - Component pads are OFF grid. No action taken.
    SMT Small Component R46-No montar (2487.284mil,4319.095mil) on Top Layer - Component pads are OFF grid. No action taken.
    SMT Small Component R45-10k (2217.284mil,4204.095mil) on Top Layer - Component pads are OFF grid. No action taken.
    SMT Small Component R43-1k (2210.827mil,1625.984mil) on Top Layer - Component pads are OFF grid. No action taken.
    SMT Small Component R42-Res2 (3661.417mil,2015.748mil) on Top Layer - Component origin is already ON grid. - Component pads are OFF grid. No action taken.
    SMT Small Component R41-Res2 (2319.055mil,2023.032mil) on Top Layer - Component pads are OFF grid. No action taken.
    SMT Small Component R40-Res2 (2394.055mil,2023.032mil) on Top Layer - Component pads are OFF grid. No action taken.
    SMT Small Component R39-Res2 (3584.409mil,2014.842mil) on Top Layer - Component pads are OFF grid. No action taken.
    SMT Small Component R38-Res2 (2839.055mil,1913.032mil) on Top Layer - Component pads are OFF grid. No action taken.
    SMT Small Component R37-Res2 (3004.055mil,2243.032mil) on Top Layer - Component pads are OFF grid. No action taken.
    SMT Small Component R36-Res2 (2819.055mil,2288.032mil) on Top Layer - Component pads are OFF grid. No action taken.
    SMT Small Component R35-Res2 (2954.055mil,1878.032mil) on Top Layer - Component pads are OFF grid. No action taken.
    SMT Small Component R34-Res2 (2902.539mil,3072.008mil) on Top Layer - Component pads are OFF grid. No action taken.
    SMT Small Component R33-Res2 (2687.539mil,2996.063mil) on Top Layer - Component pads are OFF grid. No action taken.
    SMT Small Component R32-Res2 (2263.78mil,2185.039mil) on Top Layer - Component origin is already ON grid.
    SMT Small Component R31-Res2 (2897.539mil,3321.063mil) on Top Layer - Component pads are OFF grid. No action taken.
    SMT Small Component R30-Res2 (2691.004mil,3251.063mil) on Top Layer - Component pads are OFF grid. No action taken.
    SMT Small Component R29-Res2 (1736.22mil,3665.354mil) on Top Layer - Origin changed from [1738.189mil:3665.354mil] to [1736.22mil:3665.354mil]
    SMT Small Component R28-Res2 (2452.756mil,3291.339mil) on Top Layer - Component origin is already ON grid. - Component pads are OFF grid. No action taken.
    SMT Small Component R27-Res2 (2900.669mil,2774.882mil) on Top Layer - Component pads are OFF grid. No action taken.
    SMT Small Component R26-Res2 (2695.669mil,2709.882mil) on Top Layer - Component pads are OFF grid. No action taken.
    SMT Small Component R25-Res2 (1744.094mil,2960.63mil) on Top Layer - Component origin is already ON grid. - Component pads are OFF grid. No action taken.
    SMT Small Component R24-Res2 (2460.63mil,2594.488mil) on Top Layer - Component origin is already ON grid. - Component pads are OFF grid. No action taken.
    SMT Small Component R23-Res2 (2893.701mil,2539.37mil) on Top Layer - Component origin is already ON grid.
    SMT Small Component R22-Res2 (2685.039mil,2614.173mil) on Top Layer - Component pads are OFF grid. No action taken.
    SMT Small Component R21-Res2 (6055.118mil,3744.095mil) on Top Layer - Component pads are OFF grid. No action taken.
    SMT Small Component R20-Res2 (5464.567mil,3700.787mil) on Top Layer - Component pads are OFF grid. No action taken.
    SMT Small Component R19-Res2 (4374.016mil,3763.78mil) on Top Layer - Component pads are OFF grid. No action taken.
    SMT Small Component R18-Res2 (3917.323mil,3661.417mil) on Top Layer - Origin changed from [3919.291mil:3661.417mil] to [3917.323mil:3661.417mil]
    SMT Small Component R15-Res2 (4275.591mil,2694.882mil) on Top Layer - Component pads are OFF grid. No action taken.
    SMT Small Component R14-Res2 (4275.591mil,2844.488mil) on Top Layer - Component pads are OFF grid. No action taken.
    SMT Small Component R13-Res2 (4500mil,1334.646mil) on Top Layer - Component pads are OFF grid. No action taken.
    SMT Small Component R11-Res2 (4612.756mil,1298.622mil) on Top Layer - Component pads are OFF grid. No action taken.
    SMT Small Component R8-Res2 (5594.488mil,1271.653mil) on Top Layer - Component origin is already ON grid. - Component pads are OFF grid. No action taken.
    SMT Small Component R7-No montar (4860.433mil,1395.669mil) on Top Layer - Component pads are OFF grid. No action taken.
    SMT Small Component R6-Res2 (5277.638mil,1129.685mil) on Top Layer - Component pads are OFF grid. No action taken.
    SMT Small Component R5-Res2 (4785.433mil,1395.669mil) on Top Layer - Component pads are OFF grid. No action taken.
    SMT Small Component R4-Res2 (5242.638mil,1239.685mil) on Top Layer - Component pads are OFF grid. No action taken.
    SMT Small Component R3-Res2 (4277.559mil,3187.008mil) on Top Layer - Component pads are OFF grid. No action taken.
    SMT Small Component R2-Res2 (4277.559mil,3033.464mil) on Top Layer - Component pads are OFF grid. No action taken.
    SMT Small Component Q4-IRFR1205TRPBF (1744.094mil,3385.827mil) on Top Layer - Origin changed from [1744.094mil:3386.811mil] to [1744.094mil:3385.827mil]
    SMT Small Component Q3-IRFR1205TRPBF (2177.165mil,3287.402mil) on Top Layer - Component origin is already ON grid. - Component pads are OFF grid. No action taken.
    SMT Small Component Q2-IRFR1205TRPBF (1748.032mil,2681.102mil) on Top Layer - Component origin is already ON grid. - Component pads are OFF grid. No action taken.
    SMT Small Component Q1-IRFR1205TRPBF (2177.165mil,2594.488mil) on Top Layer - Component origin is already ON grid. - Component pads are OFF grid. No action taken.
    Small Component P21-Header 3 (6830.709mil,2816.535mil) on Top Layer - Component pads are OFF grid. No action taken.
    SIP Component P19-Header 4 (6824.685mil,4219.213mil) on Top Layer - Component pads are OFF grid. No action taken.
    SIP Component P18-Header 4 (6830.709mil,3278.74mil) on Top Layer - Component pads are OFF grid. No action taken.
    SIP Component P17-Header 7 (6830.709mil,1700.787mil) on Top Layer - Component origin is already ON grid. - Component pads are OFF grid. No action taken.
    SIP Component P16-Header 4 (6834.646mil,3749.606mil) on Top Layer - Component pads are OFF grid. No action taken.
    SIP Component P15-Header 7 (6830.709mil,2457.283mil) on Top Layer - Component pads are OFF grid. No action taken.
    Small Component P14-Header 2 (3130mil,4915mil) on Top Layer - Component pads are OFF grid. No action taken.
    SIP Component P13-Header 5 (1173.228mil,3201.378mil) on Top Layer - Component pads are OFF grid. No action taken.
    Small Component P12-Header 2 (6917.323mil,4485.827mil) on Top Layer - Component pads are OFF grid. No action taken.
    SIP Component P7-Header 6 (2690.748mil,1192.913mil) on Top Layer - Component pads are OFF grid. No action taken.
    DIP Component P6-Header 7X2A (4585.039mil,1192.716mil) on Top Layer - Component pads are OFF grid. No action taken.
    SIP Component P5-Header 4 (3350.394mil,1192.913mil) on Top Layer - Component origin is already ON grid. - Component pads are OFF grid. No action taken.
    Small Component P4-Connect if local power (5750.551mil,1141.811mil) on Top Layer - Component pads are OFF grid. No action taken.
    DIP Component P3-Header 7X2A (5042.756mil,1198.622mil) on Top Layer - Component pads are OFF grid. No action taken.
    Small Component P2-Connect if power from the debugger (5870.551mil,1241.811mil) on Top Layer - Component pads are OFF grid. No action taken.
    SIP Component P1-Header 4 (3814.961mil,1196.85mil) on Top Layer - Component origin is already ON grid. - Component pads are OFF grid. No action taken.
    Component J2-691401710002B (1365mil,4768.425mil) on Top Layer - Component pads are OFF grid. No action taken.
    Component J1-691401710002B (1365mil,1325mil) on Top Layer - Component pads are OFF grid. No action taken.
    Component IC5-TLV2771CDBVR (6423.228mil,2724.409mil) on Top Layer - Component pads are OFF grid. No action taken.
    Component IC2-TLV2771CDBVR (6425.197mil,3228.347mil) on Top Layer - Component origin is already ON grid. - Component pads are OFF grid. No action taken.
    Component IC1-TLV2771CDBVR (6429.134mil,3622.047mil) on Top Layer - Component origin is already ON grid. - Component pads are OFF grid. No action taken.
    SMT Small Component FB6-120R (5428.465mil,2232.52mil) on Top Layer - Component pads are OFF grid. No action taken.
    SMT Small Component FB4-1k (5431.181mil,2308.425mil) on Top Layer - Component pads are OFF grid. No action taken.
    SMT Small Component FB3-120R (2880mil,4640mil) on Top Layer - Component pads are OFF grid. No action taken.
    SMT Small Component FB2-1k (2712.284mil,4319.095mil) on Top Layer - Component pads are OFF grid. No action taken.
    SMT Small Component FB1-1k (5992.126mil,1866.142mil) on Top Layer - Component pads are OFF grid. No action taken.
    SMT Small Component D9-LED (3462.599mil,4583.661mil) on Top Layer - Component pads are OFF grid. No action taken.
    SMT Small Component D8-Diode (2692.894mil,3101.063mil) on Top Layer - Component pads are OFF grid. No action taken.
    SMT Small Component D7-Diode (2687.539mil,3356.063mil) on Top Layer - Component pads are OFF grid. No action taken.
    SMT Small Component D6-Diode (2690.669mil,2814.882mil) on Top Layer - Component pads are OFF grid. No action taken.
    SMT Small Component D5-Diode (2681.102mil,2511.811mil) on Top Layer - Component pads are OFF grid. No action taken.
    SMT Small Component D4-LED (5125.984mil,4570.866mil) on Top Layer - Component origin is already ON grid.
    SMT Small Component D3-LED (4314.961mil,4570.866mil) on Top Layer - Component origin is already ON grid.
    SMT Small Component C126-Cap (6078.74mil,2893.701mil) on Top Layer - Component origin is already ON grid. - Component pads are OFF grid. No action taken.
    SMT Small Component C117-Cap (6417.323mil,2614.173mil) on Top Layer - Component pads are OFF grid. No action taken.
    SMT Small Component C114-Cap (6413.386mil,2913.386mil) on Top Layer - Component origin is already ON grid. - Component pads are OFF grid. No action taken.
    SMT Small Component C111-Cap (6153.543mil,3149.606mil) on Top Layer - Component origin is already ON grid. - Component pads are OFF grid. No action taken.
    SMT Small Component C110-Cap (6399.606mil,1143.701mil) on Top Layer - Component pads are OFF grid. No action taken.
    SMT Small Component C109-Cap (6330.709mil,1668.031mil) on Top Layer - Component pads are OFF grid. No action taken.
    SMT Small Component C108-Cap (6330.709mil,1748.031mil) on Top Layer - Component pads are OFF grid. No action taken.
    SMT Small Component C105-Cap (6545.276mil,1143.701mil) on Top Layer - Component pads are OFF grid. No action taken.
    SMT Small Component C104-Cap (6307.087mil,3228.347mil) on Top Layer - Component origin is already ON grid. - Component pads are OFF grid. No action taken.
    SMT Small Component C103-Cap (6364.173mil,1261.811mil) on Top Layer - Component pads are OFF grid. No action taken.
    SMT Small Component C102-Cap (6230.315mil,1297.244mil) on Top Layer - Component pads are OFF grid. No action taken.
    SMT Small Component C101-Cap (6478.347mil,1620.079mil) on Top Layer - Component pads are OFF grid. No action taken.
    SMT Small Component C100-Cap (6425.197mil,3039.37mil) on Top Layer - Component origin is already ON grid. - Component pads are OFF grid. No action taken.
    SMT Small Component C99-Cap (6482.283mil,1395.669mil) on Top Layer - Component pads are OFF grid. No action taken.
    SMT Small Component C98-Cap (6181.102mil,3393.701mil) on Top Layer - Component origin is already ON grid. - Component pads are OFF grid. No action taken.
    SMT Small Component C97-Cap (6385.827mil,1893.701mil) on Top Layer - Component origin is already ON grid. - Component pads are OFF grid. No action taken.
    SMT Small Component C96-Cap (6303.15mil,2409.449mil) on Top Layer - Component pads are OFF grid. No action taken.
    SMT Small Component C95-Cap (6299.213mil,2484.252mil) on Top Layer - Origin changed from [6301.181mil:2484.252mil] to [6299.213mil:2484.252mil]
    SMT Small Component C92-Cap (6531.496mil,1893.701mil) on Top Layer - Component origin is already ON grid. - Component pads are OFF grid. No action taken.
    SMT Small Component C91-Cap (6307.087mil,3625.984mil) on Top Layer - Component origin is already ON grid. - Component pads are OFF grid. No action taken.
    SMT Small Component C90-Cap (6362.205mil,2011.811mil) on Top Layer - Component pads are OFF grid. No action taken.
    SMT Small Component C89-Cap (6251.968mil,2047.244mil) on Top Layer - Component origin is already ON grid. - Component pads are OFF grid. No action taken.
    SMT Small Component C88-Cap (6452.756mil,2444.882mil) on Top Layer - Component origin is already ON grid. - Component pads are OFF grid. No action taken.
    SMT Small Component C87-Cap (6440.945mil,3433.071mil) on Top Layer - Component origin is already ON grid. - Component pads are OFF grid. No action taken.
    SMT Small Component C86-Cap (6448.819mil,2145.669mil) on Top Layer - Component origin is already ON grid. - Component pads are OFF grid. No action taken.
    SMT Small Component C85-Cap (5432.087mil,2465.709mil) on Top Layer - Component pads are OFF grid. No action taken.
    SMT Small Component C84-Cap (5432.087mil,2390.709mil) on Top Layer - Component pads are OFF grid. No action taken.
    SMT Small Component C83-Cap (5577.087mil,2390.709mil) on Top Layer - Component pads are OFF grid. No action taken.
    SMT Small Component C82-Cap (5577.087mil,2310.709mil) on Top Layer - Component pads are OFF grid. No action taken.
    SMT Small Component C81-Cap (5577.087mil,2235.709mil) on Top Layer - Component pads are OFF grid. No action taken.
    SMT Small Component C80-Cap (5301.181mil,2348.425mil) on Top Layer - Component pads are OFF grid. No action taken.
    SMT Small Component C77-Cap (2790mil,4640mil) on Top Layer - Component pads are OFF grid. No action taken.
    SMT Small Component C76-Cap (2705mil,4640mil) on Top Layer - Component pads are OFF grid. No action taken.
    SMT Small Component C75-Cap (2560mil,4570mil) on Top Layer - Component pads are OFF grid. No action taken.
    SMT Small Component C74-Cap (2675mil,4525mil) on Top Layer - Component pads are OFF grid. No action taken.
    Small Component C72-No montar (2710mil,4840mil) on Top Layer - Component pads are OFF grid. No action taken.
    SMT Small Component C71-0.01uF (2487.284mil,4174.095mil) on Top Layer - Component pads are OFF grid. No action taken.
    SMT Small Component C70-Cap (2595mil,4680mil) on Top Layer - Component pads are OFF grid. No action taken.
    SMT Small Component C69-Cap (1780mil,4550mil) on Top Layer - Component pads are OFF grid. No action taken.
    Small Component C68-Cap Pol2 (2935mil,4840mil) on Top Layer - Component pads are OFF grid. No action taken.
    Small Component C67-Cap Pol2 (1720mil,4865mil) on Top Layer - Component pads are OFF grid. No action taken.
    SMT Small Component C66-No montar (2637.284mil,4320.961mil) on Top Layer - Component pads are OFF grid. No action taken.
    SMT Small Component C65-10uF (2562.284mil,4320.961mil) on Top Layer - Component pads are OFF grid. No action taken.
    SMT Small Component C64-Cap (3005mil,4320mil) on Top Layer - Component pads are OFF grid. No action taken.
    SMT Small Component C63-Cap (2597.284mil,4134.095mil) on Top Layer - Component pads are OFF grid. No action taken.
    SMT Small Component C62-Cap (2597.284mil,4209.095mil) on Top Layer - Component pads are OFF grid. No action taken.
    Small Component C61-Cap Pol2 (3450mil,4285mil) on Top Layer - Component pads are OFF grid. No action taken.
    SMT Small Component C60-No montar (2177.284mil,4314.095mil) on Top Layer - Component pads are OFF grid. No action taken.
    SMT Small Component C59-Cap (2252.284mil,4314.095mil) on Top Layer - Component pads are OFF grid. No action taken.
    SMT Small Component C58-Cap (5917.323mil,1862.205mil) on Top Layer - Origin changed from [5917.323mil:1864.173mil] to [5917.323mil:1862.205mil]
    SMT Small Component C57-Cap (5842.52mil,1862.205mil) on Top Layer - Origin changed from [5842.52mil:1864.173mil] to [5842.52mil:1862.205mil]
    SMT Small Component C56-Cap (5913.386mil,1751.968mil) on Top Layer - Component pads are OFF grid. No action taken.
    SMT Small Component C55-Cap (2135.827mil,1625.984mil) on Top Layer - Component pads are OFF grid. No action taken.
    SMT Small Component C54-No montar (2515.827mil,1625.984mil) on Top Layer - Component pads are OFF grid. No action taken.
    SMT Small Component C53-Cap (2440.827mil,1625.984mil) on Top Layer - Component pads are OFF grid. No action taken.
    SMT Small Component C52-Cap (2561.339mil,2023.032mil) on Top Layer - Component pads are OFF grid. No action taken.
    SMT Small Component C51-Cap (2486.339mil,2023.032mil) on Top Layer - Component pads are OFF grid. No action taken.
    SMT Small Component C49-Cap (3114.055mil,2263.032mil) on Top Layer - Component pads are OFF grid. No action taken.
    SMT Small Component C48-Cap (2839.055mil,1839.094mil) on Top Layer - Component pads are OFF grid. No action taken.
    SMT Small Component C47-Cap (3294.055mil,2258.032mil) on Top Layer - Component pads are OFF grid. No action taken.
    SMT Small Component C46-Cap (2889.055mil,2213.032mil) on Top Layer - Component pads are OFF grid. No action taken.
    Small Component C40-Cap Pol2 (1805mil,4185mil) on Top Layer - Component pads are OFF grid. No action taken.
    Small Component C39-Cap Pol2 (1285mil,3670mil) on Top Layer - Component pads are OFF grid. No action taken.
    Small Component C38-Cap Pol2 (1286.575mil,4185mil) on Top Layer - Component pads are OFF grid. No action taken.
    Small Component C36-Cap Pol2 (1805mil,1805mil) on Top Layer - Component pads are OFF grid. No action taken.
    Small Component C35-Cap Pol2 (1285mil,1805mil) on Top Layer - Component pads are OFF grid. No action taken.
    Small Component C34-Cap Pol2 (1288.425mil,2320mil) on Top Layer - Component pads are OFF grid. No action taken.
    SMT Small Component C33-Cap (5232.283mil,3755.906mil) on Top Layer - Component pads are OFF grid. No action taken.
    Small Component C32-Cap Pol2 (5980.315mil,4023.622mil) on Top Layer - Component origin is already ON grid.
    Small Component C31-Cap Pol2 (5259.842mil,4015.748mil) on Top Layer - Component origin is already ON grid.
    SMT Small Component C30-Cap (5669.291mil,3811.024mil) on Top Layer - Component pads are OFF grid. No action taken.
    SMT Small Component C29-Cap (5834.646mil,3771.654mil) on Top Layer - Component pads are OFF grid. No action taken.
    SMT Small Component C28-Cap (5523.622mil,3811.024mil) on Top Layer - Component pads are OFF grid. No action taken.
    SMT Small Component C27-Cap (5409.449mil,4047.244mil) on Top Layer - Component pads are OFF grid. No action taken.
    SMT Small Component C26-Cap (5161.417mil,3275.59mil) on Top Layer - Component pads are OFF grid. No action taken.
    Small Component C25-Cap Pol2 (4484.252mil,4007.874mil) on Top Layer - Component origin is already ON grid.
    Small Component C24-Cap Pol2 (3771.653mil,4011.811mil) on Top Layer - Origin changed from [3771.654mil:4011.811mil] to [3771.653mil:4011.811mil]
    SMT Small Component C23-Cap (3732.284mil,3779.528mil) on Top Layer - Component origin is already ON grid. - Component pads are OFF grid. No action taken.
    SMT Small Component C22-Cap (5444.882mil,2929.134mil) on Top Layer - Component pads are OFF grid. No action taken.
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

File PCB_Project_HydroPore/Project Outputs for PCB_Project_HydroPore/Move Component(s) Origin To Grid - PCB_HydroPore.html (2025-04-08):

Date: | 13/04/2022
Time: | 21:13:20
Elapsed Time: | 00:00:01
Filename: | C:\Users\Public\Documents\Altium\Projects\PCB_Project_HydroPore\PCB_HydroPore.PcbDoc
SOIC Component U20-NCD57090ADWR2G (3497.933mil,3129.921mil) on Top Layer - Component pads are OFF grid. No action taken.
SOIC Component U15-NCD57090ADWR2G (3497.933mil,3393.701mil) on Top Layer - Component pads are OFF grid. No action taken.
SOIC Component U2-NCD57090ADWR2G (3500mil,2614.173mil) on Top Layer - Component origin is already ON grid. - Component pads are OFF grid. No action taken.
SOIC Component U1-NCD57090ADWR2G (3498.228mil,2884.843mil) on Top Layer - Component pads are OFF grid. No action taken.
SMT Small Component C94-Cap (4275.591mil,2618.11mil) on Top Layer - Component pads are OFF grid. No action taken.
SMT Small Component C93-Cap (3116.043mil,3027.559mil) on Top Layer - Component pads are OFF grid. No action taken.
SMT Small Component C79-Cap (3783.135mil,3295.279mil) on Top Layer - Component pads are OFF grid. No action taken.
SMT Small Component C78-Cap (3877.953mil,3295.276mil) on Top Layer - Component origin is already ON grid.
SMT Small Component C73-Cap (3116.043mil,3295.276mil) on Top Layer - Component pads are OFF grid. No action taken.
SMT Small Component C50-Cap (3787.402mil,2519.685mil) on Top Layer - Component origin is already ON grid.
SMT Small Component R91-Res2 (6740.158mil,4401.575mil) on Top Layer - Component origin is already ON grid. - Component pads are OFF grid. No action taken.
SMT Small Component R90-Res2 (5933.071mil,4377.953mil) on Top Layer - Component origin is already ON grid. - Component pads are OFF grid. No action taken.
SMT Small Component R89-Res2 (5125.984mil,4377.953mil) on Top Layer - Component origin is already ON grid. - Component pads are OFF grid. No action taken.
SMT Small Component R88-Res2 (4311.024mil,4381.89mil) on Top Layer - Component origin is already ON grid. - Component pads are OFF grid. No action taken.
SMT Small Component D11-LED (6736.221mil,4570.866mil) on Top Layer - Component origin is already ON grid.
SMT Small Component D10-LED (5933.071mil,4570.866mil) on Top Layer - Component origin is already ON grid.
SMT Small Component R87-Res2 (6545.276mil,2795.276mil) on Top Layer - Component pads are OFF grid. No action taken.
SMT Small Component R86-Res2 (6578.74mil,2685.039mil) on Top Layer - Origin changed from [6576.772mil:2685.039mil] to [6578.74mil:2685.039mil]
SMT Small Component R85-Res2 (6543.307mil,3102.362mil) on Top Layer - Component origin is already ON grid. - Component pads are OFF grid. No action taken.
SMT Small Component R84-Res2 (6578.74mil,3232.284mil) on Top Layer - Component origin is already ON grid. - Component pads are OFF grid. No action taken.
SMT Small Component R83-Res2 (6578.74mil,3307.087mil) on Top Layer - Component origin is already ON grid. - Component pads are OFF grid. No action taken.
SMT Small Component R44-Res2 (6437.008mil,3736.22mil) on Top Layer - Origin changed from [6438.976mil:3736.22mil] to [6437.008mil:3736.22mil]
SMT Small Component Y2-CRYSTAL (4759.842mil,2425.197mil) on Top Layer - Component origin is already ON grid. - Component pads are OFF grid. No action taken.
SMT Small Component C45-Cap (4661.417mil,2271.653mil) on Top Layer - Component pads are OFF grid. No action taken.
SMT Small Component C44-Cap (4862.205mil,2271.653mil) on Top Layer - Component pads are OFF grid. No action taken.
Component J6-RJ11-6N-B (6455.118mil,4299.606mil) on Top Layer - Component pads are OFF grid. No action taken.
Component J5-RJ11-6N-B (5651.969mil,4295.669mil) on Top Layer - Component pads are OFF grid. No action taken.
Component J4-RJ11-6N-B (4844.882mil,4295.669mil) on Top Layer - Component pads are OFF grid. No action taken.
Component J3-RJ11-6N-B (4033.858mil,4299.606mil) on Top Layer - Component pads are OFF grid. No action taken.
SMT Small Component C43-Cap (6478.347mil,1545.276mil) on Top Layer - Component pads are OFF grid. No action taken.
SMT Small Component C42-Cap (6452.756mil,2370.079mil) on Top Layer - Component pads are OFF grid. No action taken.
SMT Small Component R47-1k (3245mil,4210mil) on Top Layer - Component pads are OFF grid. No action taken.
SMT Small Component Y1-CRYSTAL (5311.024mil,2889.764mil) on Top Layer - Component pads are OFF grid. No action taken.
SMT Small Component VR1-NCP1117DT50G (2177.716mil,4685mil) on Top Layer - Component pads are OFF grid. No action taken.
SOIC Component U19-MAX11101EUBT (6299.213mil,2240.157mil) on Top Layer - Component origin is already ON grid. - Component pads are OFF grid. No action taken.
SOIC Component U18-MAX11101EUBT (6312.992mil,1490.158mil) on Top Layer - Component pads are OFF grid. No action taken.
SOIC Component U17-AD8293G160ARJZ-R7 (6490.158mil,1265.748mil) on Top Layer - Component pads are OFF grid. No action taken.
SOIC Component U16-AD8293G160ARJZ-R7 (6464.567mil,2019.685mil) on Top Layer - Component pads are OFF grid. No action taken.
SMT SIP Component U14-LF50ABPT-TR (3195mil,4486.181mil) on Top Layer - Component pads are OFF grid. No action taken.
Component U13-REG113NA-3.3/250 (2366.102mil,4316.693mil) on Top Layer - Component pads are OFF grid. No action taken.
Component U12-LD2981ABM50TR (2324.646mil,1623.386mil) on Top Layer - Component pads are OFF grid. No action taken.
SOIC Component U11-ADUM210N1BRIZ (3300.354mil,2080.157mil) on Top Layer - Component pads are OFF grid. No action taken.
SOIC Component U10-MCP6567-E/SN (2814.055mil,2063.032mil) on Top Layer - Component pads are OFF grid. No action taken.
SOIC Component U9-TS5A3157DBVR (5944.882mil,3767.717mil) on Top Layer - Component pads are OFF grid. No action taken.
SOIC Component U8-TS5A3157DBVR (5354.331mil,3767.717mil) on Top Layer - Component pads are OFF grid. No action taken.
SOIC Component U7-MAX232IDR (5657.48mil,4027.559mil) on Top Layer - Component pads are OFF grid. No action taken.
SOIC Component U6-TS5A3157DBVR (3854.331mil,3787.402mil) on Top Layer - Component origin is already ON grid. - Component pads are OFF grid. No action taken.
SOIC Component U5-MAX232IDR (4163.583mil,4012.441mil) on Top Layer - Component pads are OFF grid. No action taken.
SOIC Component U4-TS5A3157DBVR (4488.189mil,3783.465mil) on Top Layer - Component origin is already ON grid. - Component pads are OFF grid. No action taken.
LCC Component U3-MSP430F6459TPZR (4896.102mil,2875.118mil) on Top Layer - Component pads are OFF grid. No action taken.
Small Component S1-SW-SPST (5417.638mil,1264.685mil) on Top Layer - Component pads are OFF grid. No action taken.
SMT Small Component R79-Res2 (6303.15mil,2889.764mil) on Top Layer - Component origin is already ON grid. - Component pads are OFF grid. No action taken.
SMT Small Component R78-Res2 (6188.976mil,2929.134mil) on Top Layer - Component origin is already ON grid. - Component pads are OFF grid. No action taken.
SMT Small Component R71-Res2 (6413.386mil,2838.583mil) on Top Layer - Component origin is already ON grid. - Component pads are OFF grid. No action taken.
SMT Small Component R70-Res2 (6303.15mil,2740.157mil) on Top Layer - Component origin is already ON grid. - Component pads are OFF grid. No action taken.
SMT Small Component R69-No montar (6214.567mil,1702.756mil) on Top Layer - Component pads are OFF grid. No action taken.
SMT Small Component R68-Res2 (6228.346mil,3149.606mil) on Top Layer - Component origin is already ON grid. - Component pads are OFF grid. No action taken.
SMT Small Component R67-Res2 (6275.591mil,3039.37mil) on Top Layer - Origin changed from [6277.559mil:3039.37mil] to [6275.591mil:3039.37mil]
SMT Small Component R66-10k (6198.819mil,1478.346mil) on Top Layer - Component pads are OFF grid. No action taken.
SMT Small Component R65-Res2 (6425.197mil,3114.173mil) on Top Layer - Component origin is already ON grid. - Component pads are OFF grid. No action taken.
SMT Small Component R64-Res2 (6551.181mil,3692.913mil) on Top Layer - Component origin is already ON grid. - Component pads are OFF grid. No action taken.
SMT Small Component R63-Res2 (6592.52mil,1435.039mil) on Top Layer - Component pads are OFF grid. No action taken.
SMT Small Component R62-Res2 (6482.283mil,1470.472mil) on Top Layer - Component pads are OFF grid. No action taken.
SMT Small Component R61-No montar (6173.228mil,2444.882mil) on Top Layer - Component pads are OFF grid. No action taken.
SMT Small Component R60-Res2 (6271.654mil,3507.874mil) on Top Layer - Component origin is already ON grid. - Component pads are OFF grid. No action taken.
SMT Small Component R59-Res2 (6291.339mil,3433.071mil) on Top Layer - Component origin is already ON grid. - Component pads are OFF grid. No action taken.
SMT Small Component R58-10k (6173.228mil,2204.724mil) on Top Layer - Component pads are OFF grid. No action taken.
SMT Small Component R57-Res2 (6440.945mil,3507.874mil) on Top Layer - Component origin is already ON grid. - Component pads are OFF grid. No action taken.
SMT Small Component R56-Res2 (6551.181mil,3547.244mil) on Top Layer - Component origin is already ON grid. - Component pads are OFF grid. No action taken.
SMT Small Component R55-Res2 (6452.756mil,2295.276mil) on Top Layer - Component origin is already ON grid. - Component pads are OFF grid. No action taken.
SMT Small Component R54-Res2 (6448.819mil,2220.472mil) on Top Layer - Origin changed from [6450.787mil:2220.472mil] to [6448.819mil:2220.472mil]
SMT Small Component R52-Res2 (5261.181mil,2233.425mil) on Top Layer - Component pads are OFF grid. No action taken.
SMT Small Component R51-Res2 (3230mil,4815mil) on Top Layer - Component pads are OFF grid. No action taken.
SMT Small Component R50-Cortocircuitar (1810mil,4660mil) on Top Layer - Component pads are OFF grid. No action taken.
SMT Small Component R49-No montar (2372.284mil,4209.095mil) on Top Layer - Component pads are OFF grid. No action taken.
SMT Small Component R48-No montar (2565mil,4883.465mil) on Top Layer - Component pads are OFF grid. No action taken.
SMT Small Component R46-No montar (2487.284mil,4319.095mil) on Top Layer - Component pads are OFF grid. No action taken.
SMT Small Component R45-10k (2217.284mil,4204.095mil) on Top Layer - Component pads are OFF grid. No action taken.
SMT Small Component R43-1k (2210.827mil,1625.984mil) on Top Layer - Component pads are OFF grid. No action taken.
SMT Small Component R42-Res2 (3661.417mil,2015.748mil) on Top Layer - Component origin is already ON grid. - Component pads are OFF grid. No action taken.
SMT Small Component R41-Res2 (2319.055mil,2023.032mil) on Top Layer - Component pads are OFF grid. No action taken.
SMT Small Component R40-Res2 (2394.055mil,2023.032mil) on Top Layer - Component pads are OFF grid. No action taken.
SMT Small Component R39-Res2 (3584.409mil,2014.842mil) on Top Layer - Component pads are OFF grid. No action taken.
SMT Small Component R38-Res2 (2839.055mil,1913.032mil) on Top Layer - Component pads are OFF grid. No action taken.
SMT Small Component R37-Res2 (3004.055mil,2243.032mil) on Top Layer - Component pads are OFF grid. No action taken.
SMT Small Component R36-Res2 (2819.055mil,2288.032mil) on Top Layer - Component pads are OFF grid. No action taken.
SMT Small Component R35-Res2 (2954.055mil,1878.032mil) on Top Layer - Component pads are OFF grid. No action taken.
SMT Small Component R34-Res2 (2902.539mil,3072.008mil) on Top Layer - Component pads are OFF grid. No action taken.
SMT Small Component R33-Res2 (2687.539mil,2996.063mil) on Top Layer - Component pads are OFF grid. No action taken.
SMT Small Component R32-Res2 (2263.78mil,2185.039mil) on Top Layer - Component origin is already ON grid.
SMT Small Component R31-Res2 (2897.539mil,3321.063mil) on Top Layer - Component pads are OFF grid. No action taken.
SMT Small Component R30-Res2 (2691.004mil,3251.063mil) on Top Layer - Component pads are OFF grid. No action taken.
SMT Small Component R29-Res2 (1736.22mil,3665.354mil) on Top Layer - Origin changed from [1738.189mil:3665.354mil] to [1736.22mil:3665.354mil]
SMT Small Component R28-Res2 (2452.756mil,3291.339mil) on Top Layer - Component origin is already ON grid. - Component pads are OFF grid. No action taken.
SMT Small Component R27-Res2 (2900.669mil,2774.882mil) on Top Layer - Component pads are OFF grid. No action taken.
SMT Small Component R26-Res2 (2695.669mil,2709.882mil) on Top Layer - Component pads are OFF grid. No action taken.
SMT Small Component R25-Res2 (1744.094mil,2960.63mil) on Top Layer - Component origin is already ON grid. - Component pads are OFF grid. No action taken.
SMT Small Component R24-Res2 (2460.63mil,2594.488mil) on Top Layer - Component origin is already ON grid. - Component pads are OFF grid. No action taken.
SMT Small Component R23-Res2 (2893.701mil,2539.37mil) on Top Layer - Component origin is already ON grid.
SMT Small Component R22-Res2 (2685.039mil,2614.173mil) on Top Layer - Component pads are OFF grid. No action taken.
SMT Small Component R21-Res2 (6055.118mil,3744.095mil) on Top Layer - Component pads are OFF grid. No action taken.
SMT Small Component R20-Res2 (5464.567mil,3700.787mil) on Top Layer - Component pads are OFF grid. No action taken.
SMT Small Component R19-Res2 (4374.016mil,3763.78mil) on Top Layer - Component pads are OFF grid. No action taken.
SMT Small Component R18-Res2 (3917.323mil,3661.417mil) on Top Layer - Origin changed from [3919.291mil:3661.417mil] to [3917.323mil:3661.417mil]
SMT Small Component R15-Res2 (4275.591mil,2694.882mil) on Top Layer - Component pads are OFF grid. No action taken.
SMT Small Component R14-Res2 (4275.591mil,2844.488mil) on Top Layer - Component pads are OFF grid. No action taken.
SMT Small Component R13-Res2 (4500mil,1334.646mil) on Top Layer - Component pads are OFF grid. No action taken.
SMT Small Component R11-Res2 (4612.756mil,1298.622mil) on Top Layer - Component pads are OFF grid. No action taken.
SMT Small Component R8-Res2 (5594.488mil,1271.653mil) on Top Layer - Component origin is already ON grid. - Component pads are OFF grid. No action taken.
SMT Small Component R7-No montar (4860.433mil,1395.669mil) on Top Layer - Component pads are OFF grid. No action taken.
SMT Small Component R6-Res2 (5277.638mil,1129.685mil) on Top Layer - Component pads are OFF grid. No action taken.
SMT Small Component R5-Res2 (4785.433mil,1395.669mil) on Top Layer - Component pads are OFF grid. No action taken.
SMT Small Component R4-Res2 (5242.638mil,1239.685mil) on Top Layer - Component pads are OFF grid. No action taken.
SMT Small Component R3-Res2 (4277.559mil,3187.008mil) on Top Layer - Component pads are OFF grid. No action taken.
SMT Small Component R2-Res2 (4277.559mil,3033.464mil) on Top Layer - Component pads are OFF grid. No action taken.
SMT Small Component Q4-IRFR1205TRPBF (1744.094mil,3385.827mil) on Top Layer - Origin changed from [1744.094mil:3386.811mil] to [1744.094mil:3385.827mil]
SMT Small Component Q3-IRFR1205TRPBF (2177.165mil,3287.402mil) on Top Layer - Component origin is already ON grid. - Component pads are OFF grid. No action taken.
SMT Small Component Q2-IRFR1205TRPBF (1748.032mil,2681.102mil) on Top Layer - Component origin is already ON grid. - Component pads are OFF grid. No action taken.
SMT Small Component Q1-IRFR1205TRPBF (2177.165mil,2594.488mil) on Top Layer - Component origin is already ON grid. - Component pads are OFF grid. No action taken.
Small Component P21-Header 3 (6830.709mil,2816.535mil) on Top Layer - Component pads are OFF grid. No action taken.
SIP Component P19-Header 4 (6824.685mil,4219.213mil) on Top Layer - Component pads are OFF grid. No action taken.
SIP Component P18-Header 4 (6830.709mil,3278.74mil) on Top Layer - Component pads are OFF grid. No action taken.
SIP Component P17-Header 7 (6830.709mil,1700.787mil) on Top Layer - Component origin is already ON grid. - Component pads are OFF grid. No action taken.
SIP Component P16-Header 4 (6834.646mil,3749.606mil) on Top Layer - Component pads are OFF grid. No action taken.
SIP Component P15-Header 7 (6830.709mil,2457.283mil) on Top Layer - Component pads are OFF grid. No action taken.
Small Component P14-Header 2 (3130mil,4915mil) on Top Layer - Component pads are OFF grid. No action taken.
SIP Component P13-Header 5 (1173.228mil,3201.378mil) on Top Layer - Component pads are OFF grid. No action taken.
Small Component P12-Header 2 (6917.323mil,4485.827mil) on Top Layer - Component pads are OFF grid. No action taken.
SIP Component P7-Header 6 (2690.748mil,1192.913mil) on Top Layer - Component pads are OFF grid. No action taken.
DIP Component P6-Header 7X2A (4585.039mil,1192.716mil) on Top Layer - Component pads are OFF grid. No action taken.
SIP Component P5-Header 4 (3350.394mil,1192.913mil) on Top Layer - Component origin is already ON grid. - Component pads are OFF grid. No action taken.
Small Component P4-Connect if local power (5750.551mil,1141.811mil) on Top Layer - Component pads are OFF grid. No action taken.
DIP Component P3-Header 7X2A (5042.756mil,1198.622mil) on Top Layer - Component pads are OFF grid. No action taken.
Small Component P2-Connect if power from the debugger (5870.551mil,1241.811mil) on Top Layer - Component pads are OFF grid. No action taken.
SIP Component P1-Header 4 (3814.961mil,1196.85mil) on Top Layer - Component origin is already ON grid. - Component pads are OFF grid. No action taken.
Component J2-691401710002B (1365mil,4768.425mil) on Top Layer - Component pads are OFF grid. No action taken.
Component J1-691401710002B (1365mil,1325mil) on Top Layer - Component pads are OFF grid. No action taken.
Component IC5-TLV2771CDBVR (6423.228mil,2724.409mil) on Top Layer - Component pads are OFF grid. No action taken.
Component IC2-TLV2771CDBVR (6425.197mil,3228.347mil) on Top Layer - Component origin is already ON grid. - Component pads are OFF grid. No action taken.
Component IC1-TLV2771CDBVR (6429.134mil,3622.047mil) on Top Layer - Component origin is already ON grid. - Component pads are OFF grid. No action taken.
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

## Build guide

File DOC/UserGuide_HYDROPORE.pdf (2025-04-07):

# GUÍA DE USUARIO DEL MONTAJE EXPERIMENTAL ‘HYDROPORE’

Autor: Arnau Quintana Llorens

El presente documento tiene el objetivo de resumir cómo trabajar con el sistema: desde las conexiones a unas pautas que deben seguirse para que todo funcione según lo esperado.

## CONTROL DE CAMBIOS

Autor | Apartado | Fecha | Versión
Arnau Quintana | TODOS | 18-09-2022 | 0

## ÍNDICE

## CONEXIONES EN LA PCB

Alimentaciones
Encontramos dos conectores para las entradas de alimentación, una de 15V y otra de 12V. Es muy importante no confundirlas pues el sistema puede no funcionar e incluso podría romperse algún componente. La entrada de 12V alimenta el puente H, es decir, si conectáramos sólo la fuente de 15V, toda la parte de los sensores, las cámaras y el microcontrolador, funcionaría sin problema.

Tenemos además una entrada de 5V auxiliar, está destinada únicamente a la programación del microcontrolador, no está pensada para alimentar otra parte del sistema. Puede ser útil si queremos mandar algún comando o para reprogramar el controlador en caso necesario. Cabe recalcar que NO debemos conectar la fuente de 15V y la entrada de 5V a la vez, la entrada de 15V ya proporciona al circuito los 5V necesarios, pero la entrada auxiliar nos evitar pasar por los reguladores.

NO DEBEMOS CONECTAR NUNCA LA ENTRADA DE 5V AUXILIAR, SÓLO ESTÁ PENSADA PARA QUE LA USE EL PROGRAMADOR, NO EL USUARIO.

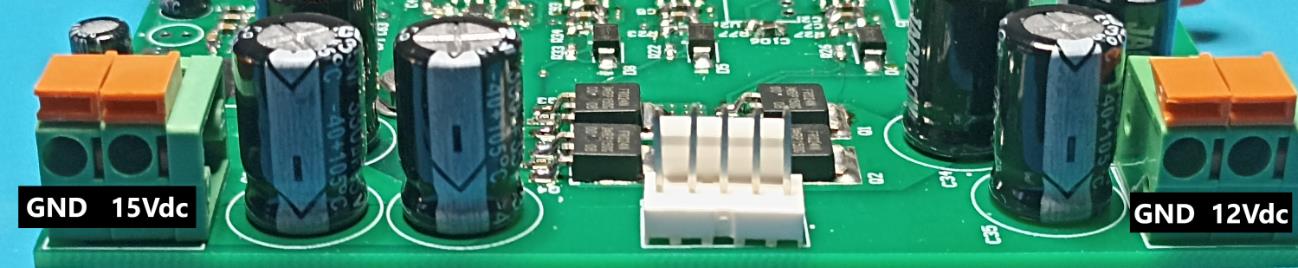
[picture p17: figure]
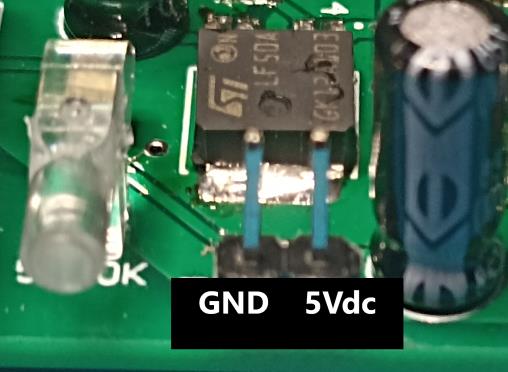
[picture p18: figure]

Actuador
En la PCB, el conector para el actuador tiene un total de 5pines: + y – del actuador que corresponden a la alimentación y +, - y salida del feedback que nos proporciona. En caso de querer cambiar el actuador, deberá cumplir las siguientes características:
- Alimentación de 12V.
- Bipolaridad, es decir, que permita ambas polaridades para poder ser usado con un puente en H.

Si el próximo actuador no tiene opción de feedback, se deberá modificar el software.

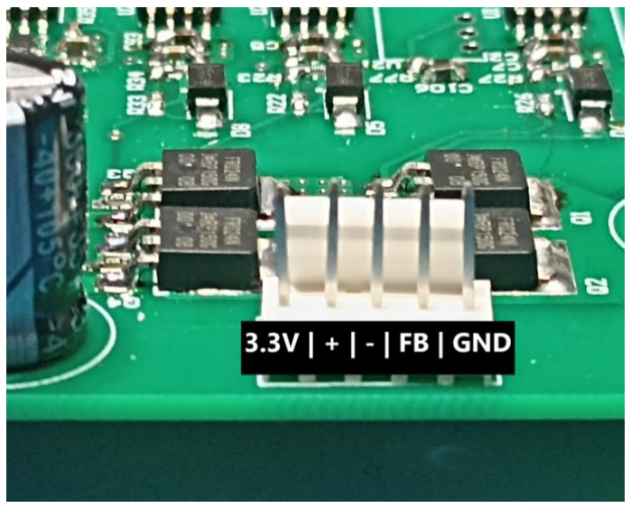
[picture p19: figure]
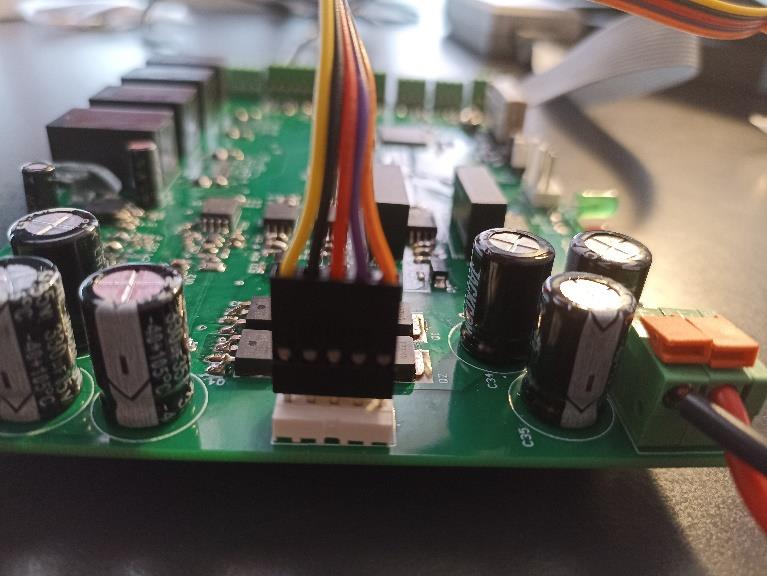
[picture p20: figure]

Sensores

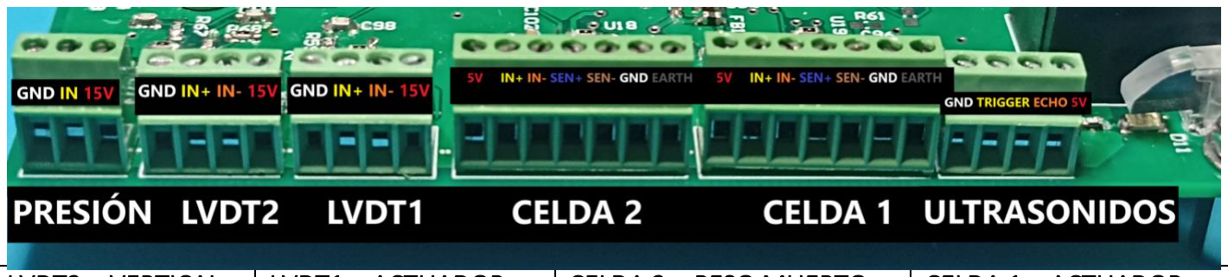
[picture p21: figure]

LVDT2 = VERTICAL | LVDT1 = ACTUADOR | CELDA 2 = PESO MUERTO | CELDA 1 = ACTUADOR
*Los colores de la imagen no coinciden con los colores de los cables reales, mirar el apartado de cada sensor para ello.

### Sensor de ultrasonidos

Encontraremos un total de 4 pines: 5V, GND, ECHO y TRIGGER.

Los 5V indican la alimentación positiva del módulo. El pin etiquetado como GND indica la referencia del módulo. Deberemos conectar los pines tal como se indica en la siguiente imagen.

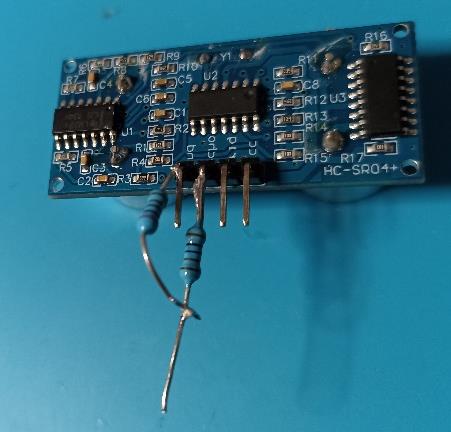
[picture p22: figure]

### Celdas de carga

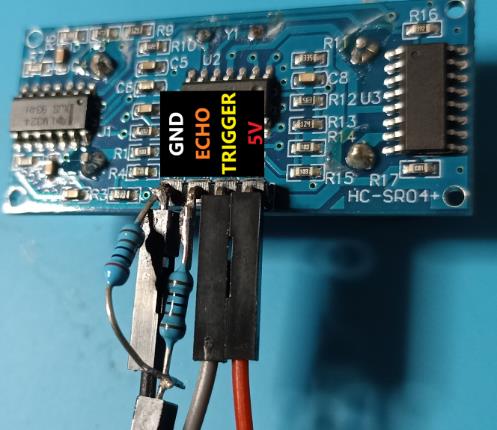
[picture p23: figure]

La PCB permite celdas de 6 cables, donde 4 de ellos son los corrientes de un puente de Wheatstone: alimentación (en este caso 5V), la masa, entrada negativa y la positiva. En este caso también tenemos la opción de usar las referencias proporcionadas por la misma celda al ADC. Si usáramos una celda que no tuviera esos 2 cables, deberíamos hacer ajustes en la placa. La entrada ‘EARTH’ no la usaremos, veremos que la celda no dispone de 7 cables si no de 6.

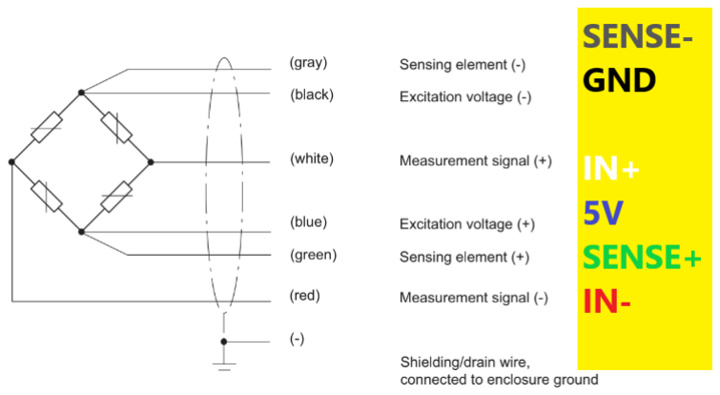
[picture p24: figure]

La salía de las celdas es de 2mV/V, si cambiamos esa característica, implicaría cambios en hardware y software.

### LVDTs

El LVDT que la PCB permite, pueden ser de 3 o 4 cables, aunque nosotros usamos los 4 cables: entrada negativa, entrada positiva, masa y 15Vdc. Si quisiéramos usar otro LVDT debemos asegurarnos de que permite alimentación de 15Vdc y su salida oscila de 0 a 6V según la extensión del núcleo (cuanto más se adentre el núcleo al cuerpo del LVDT, más tensión hay en la salida). Podríamos conectar uno de 3 cables simplemente cortocircuitando la entrada negativa con masa, eso sí, habría que revisar el software.

Si la salida del nuevo LVDT es distinta, se deberá dimensionar de nuevo el circuito y revisar que el software no necesite algún ajuste, ya que el microcontrolador calcula el valor analógico a partir de los datos de la hoja de especificaciones del sensor.

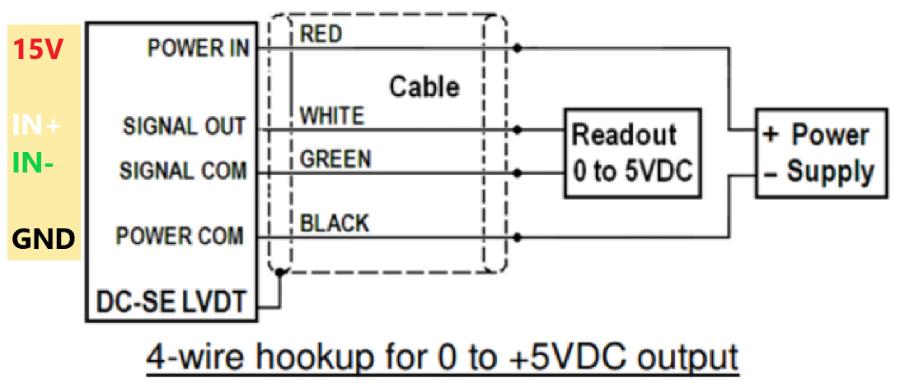
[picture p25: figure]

### Sensor de presión del agua

El conexionado es muy parecido al LVDT, pero en este caso no tenemos entrada negativa, sólo positiva, alimentación de 15V y masa. La salida también debe oscilar entre 0 y 5V.

Cámaras y Arduino

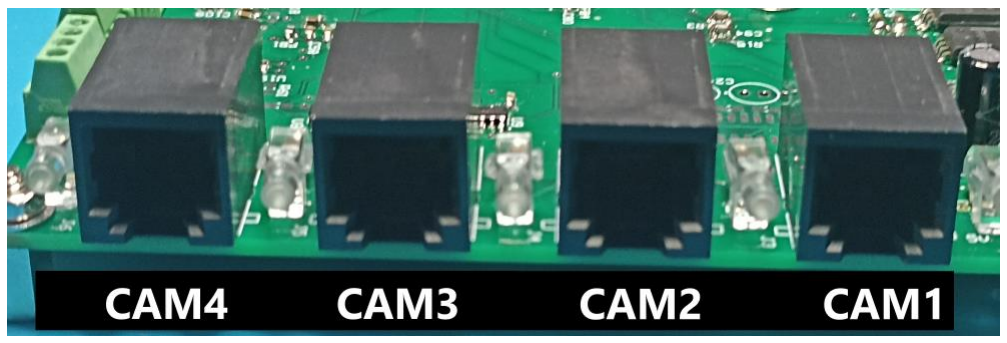
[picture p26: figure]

Para conectar las cámaras a la PCB el usuario debe preocuparse del orden en que las conecta.

Cuando queramos importar las fotografías deberemos extraer la tarjeta SD del grabador y conectarla al ordenador mediante el adaptador a un puerto USB 3.0 o USB C.

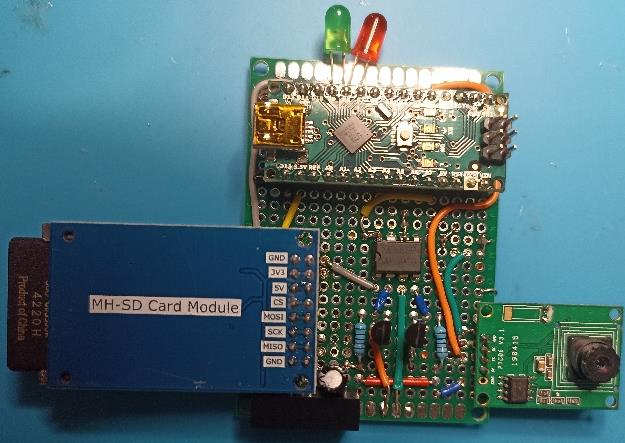
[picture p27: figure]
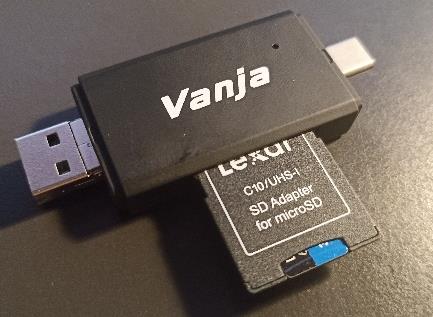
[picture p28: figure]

En caso de que en el arranque el Arduino no detecte la cámara o la tarjeta SD, el led rojo que acompaña a montaje de las cámaras parpadeará. Deberemos revisar las conexiones y pulsar el botón ‘RESET’, que se encuentra en el centro de la placa, para que la máquina inicie el programa de nuevo.

Cuando Arduino esté listo para recibir un ‘trigger’ el LED verde se mantendrá encendido. Una vez reciba un ‘trigger’, el LED verde se apagará y el rojo se encenderá indicando ‘sistema ocupado’. Cuando se tome una fotografía correctamente y se guarde en la tarjeta, el LED verde se encenderá por 1 segundos. Mientras el sistema está ocupado podemos mandar igualmente un ‘trigger’ si queremos parar de tomar imágenes, Arduino lo leerá cuando acabe de guardar la última imagen.

FTDI (USB A UART)
Este dispositivo nos ayuda a traducir las instrucciones desde el ordenador con el protocolo USB al protocolo UART para que el microcontrolador que controla el sistema pueda entenderlos. También hace la acción inversa, traduce los datos enviados por UART del microcontrolador para que el PC pueda entenderlo.

La particularidad de esta conexión es que debemos cruzar RX con TX, es decir, el pin etiquetado como RX en el dispositivo debe ir al pin etiquetado como TX en la PCB, y el pin etiquetado como TX en el dispositivo debe ir al pin etiquetado como RX en la PCB. NO debemos conectar el 3.3V del FTDI al pin del PCB, es decir, de los 4 pines que vemos en la imagen inferior sólo conectaremos 3. Esto es debido a que no necesitamos los 3.3V que nos proporciona el dispositivo ya que la PCB los genera. Es muy importante realizar correctamente esta conexión pues de no ser así, el PC y el microcontrolador no se entenderán y por muchos comandos que mandemos, el sistema no reaccionará. En la siguiente imagen se puede ver de manera más visual cómo debemos conectar el FTDI a la PCB, los nombres que aparecen corresponden a dónde deben ir los cables del FTDI, es decir, se ha etiquetado para que el TX del FTDI deba ir al TX que se muestra en la foto:

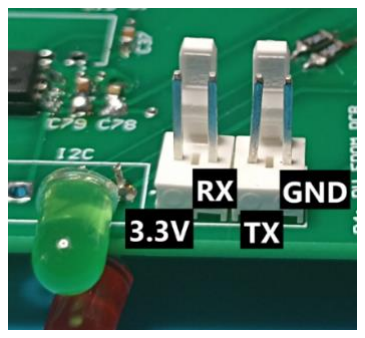
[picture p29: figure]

Dispositivo I2C
En la PCB hemos dejado un conector etiquetado como I2C. En el montaje inicial ese conector no está montado y en su lugar hay 2 LEDS, uno rojo y otro verde. Este espacio está dedicado a un dispositivo que informe de manera visual al usuario del estado del sistema. Se ha creído más práctico usar 2 LEDS para ese fin, pero si en algún momento se quisiera usar una pantalla LCD o un dispositivo que se controle mediante el protocolo I2C, únicamente deberíamos conectar el pin etiquetado en la PCB como SCL al pin etiquetado como SCL en el dispositivo, y el pin SDA de la PCB al pin SDA del dispositivo. Tenemos otros 2 pines que corresponden a 5V y GND, es decir, podríamos alimentar el dispositivo que conectáramos directamente desde la PCB, eso sí, debe soportar esos 5V de alimentación.

Cabe recalcar que, de conectar un dispositivo nuevo, debería modificarse el software, ya que no está previsto que se conecte un nuevo componente.

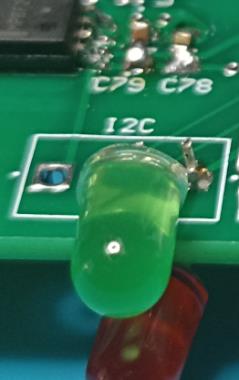
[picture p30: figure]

## TRABAJANDO CON EL SISTEMA

LEDs indicadores en la PCB
LED VERDE | LED ROJO | SIGNIFICADO
ON | OFF | A LA ESPERA DE UN COMANDO
OFF | PARPADEA | ERROR*
ON | ON | PRIMER COMANDO OK, A LA ESPERA DEL SEGUNDO
OFF | ON | NO MANDAR COMANDOS, SISTEMA TRABAJANDO
PARPADEA | PARPADEA | ERROR DEL PUENTE H POR SOBRECORRIENTE*
ON | PARPADEA | ERROR EN MOVIMIENTO DEL ACTUADOR*
*Consultar el apartado ‘Posibles fuentes de error’ en la página 12.

LEDs junto a los conectores de las cámaras en la PCB
LED VERDE | SIGNIFICADO
ON (2 SECS) | TRIGGER ENVIADO CORRECTAMENTE
OFF | NO HAY COMUNICACÓN
PARPADEA | ERROR AL ENVIAR EL TRIGGER*
*Consultar el apartado ‘Posibles fuentes de error’ en la página 12.

LEDs en módulo de las cámaras
LED VERDE | LED ROJO | SIGNIFICADO
OFF | ON | SISTEMA TRABAJANDO
OFF | PARPADEA | ERROR AL NO ENCONTRAR CÁMARA O SD*
ON (1 SEG) | OFF | FOTO TOMADA Y GUARDADA EN SD
ON | OFF | ESPERANDO A UN TRIGGER, SIN TOMAR FOTOS
*Consultar el apartado ‘Posibles fuentes de error’ en la página 12.

Comandos posibles dentro del sistema
Módulo | Acción
ACTUADOR | MOVER ADELANTE 1mm
MOVER HACIA ATRÁS 1mm
AUMENTAR VELOCIDAD 1%
REDUCIR VELOCIDAD 1%
POSICIÓN INICIAL (ACTUADOR COMPLETAMENTE RETRAÍDO)

SENSORES

COGER 5 DATOS DEL LVDT HORIZONTAL COGER 5 DATOS DEL LVDT VERTICAL COGER 5 DATOS DE LA CELDA DE CARGA DEL ACTUADOR COGER 5 DATOS DE LA CELDA DE CARGA DEL PESO MUERTO COGER 5 DATOS DEL SENSOR DE PRESIÓN DEL AGUA COGER 5 DATOS DEL FEEDBACK DEL ACTUADOR

CÁMARAS

EMPEZAR/PARAR A TOMAR FOTOS CON LA CÁMARA 1 EMPEZAR/PARAR A TOMAR FOTOS CON LA CÁMARA 2 EMPEZAR/PARAR A TOMAR FOTOS CON LA CÁMARA 3 EMPEZAR/PARAR A TOMAR FOTOS CON LA CÁMARA 4 EMPEZAR/PARAR A TOMAR FOTOS CON TODAS LAS CÁMARAS
COMPLETE | EJECUTAR EL PROGRAMA COMPLETO
TEST | COGER DATO DE TODOS LOS TRANSDUCTORES, SIN MOVER EL ACTUADOR

Instrucciones antes de trabajar con el sistema
El sistema no reaccionará hasta que el usuario envíe un comando. En caso de querer ejecutar todo el programa completo, sólo deberemos mandar un comando. En caso de querer direccionar la instrucción a un módulo en particular, deberemos indicar primero el módulo y luego la parte del módulo. Por ejemplo:
- Queremos datos del LVDT horizontal -> debemos mandar el comando del módulo de los sensores y, a continuación, mandar el comando del LVDT horizontal.

El envío de comandos al sistema se realiza a través de una aplicación con interfaz en el ordenador, es decir, debemos tener un ordenador con Python3 instalado siempre disponible para poder interactuar con el sistema. El usuario únicamente debe indicar mediante los botones que acción quiere realizar con el sistema. Una vez mandemos el comando, no podremos corregirlo, es decir, no existe la instrucción ‘deshacer’. Si nos hemos equivocado en el comando, deberemos actuar en consecuencia.

ES MUY IMPORTANTE, si queremos realizar algún movimiento con el actuador, como mínimo tener conectado al sistema: el ultrasonidos, el LVDT horizontal y el actuador. Si no tenemos alguno de estos componentes conectados, el sistema nos devolverá valores bajos del LVDT y aleatorios del feedback. Podemos usar el sistema aun no teniendo conectado el ultrasonidos, es una protección extra y ya se ha tenido en cuenta mediante el software que podemos o no tenerlo conectado. El sistema tiene protecciones para que no se quede colgado, es decir, si nos olvidamos de conectar algún sensor, lo peor que puede pasar es que las medidas sean incorrectas y tengamos que descartarlas. Si queremos movernos hacia adelante, pero nos falta por conectar o el actuador o el LVDT, pueden darse dos situaciones:

-Si no tenemos el actuador conectado, el sistema nos devolverá un error directamente porque no puede mover el motor. Lo mismo pasaría si intentemos movernos hacia atrás.

-Si no tenemos conectado el LVDT pero sí el actuador, el sistema moverá el actuador, pero cuando detecte que las medidas del LVDT no varían, parará el motor y nos devolverá un error.

Para evitar este tipo de situaciones, debemos pedir datos a los sensores y ver que el resultado cuadra con lo que esperamos. Estos son los valores que recibiremos si los sensores están desconectados:

Sensor | Medida
LVDT | 0.012 – 0.015 mm
Sensor de presión | 0.012 – 0.015 bar
Celda de carga | 312.462 N

ES MUY IMPORTANTE, calibrar el sistema antes de empezar a moverlo. Debemos coger, como mínimo, un dato del LVDT horizontal y un dato del ‘feedback’ del actuador. Podemos hacerlo, o bien accediendo al módulo individualmente, o ejecutando el comando ‘TEST’. Si intentamos mover la estructura sin haber calibrado el sistema, nos devolverá un ERROR.

Los movimientos hacia adelante se miden con el LVDT, por lo que la precisión será muy buena. Los movimientos hacia atrás se miden con el ‘feedback’ del actuador, por lo que no serán tan precisos como si lo hiciéramos con el LVDT. Esto es debido a que la base no está enganchada al actuador, por lo que, si movemos hacia atrás el motor, la base no se moverá con él.

Cada vez que movamos el actuador hacia atrás deberemos volver a coger un dato del LVDT para recalibrarlo, pues como no trabaja en esos movimientos, desconocerá dónde está la base.

Podremos ejecutar el ‘programa completo’ hasta los 10mm de desplazamiento, independientemente de la posición en que iniciemos, es decir, la posición 10mm siempre se sitúa en el mismo lugar. Si probamos a ejecutar el programa completo estando en la posición máxima el sistema nos dará ERROR. Si quisiéramos coger los datos de los sensores estando en la posición máxima de desplazamiento podemos ir uno por uno, o usar el botón de ‘TEST’.

ES MUY IMPORTANTE, desconectar la alimentación del sistema si pretendemos mover o cambiar de posición algún sensor. NO debemos manipular nada con el sistema alimentado. Hay que tener en cuenta que una vez se apague la alimentación el sistema se reinicia.

Si quisiéramos manipular la PCB y necesitáramos desconectar los cables de alimentación, es muy importante primero haber desconectado la fuente de la red y, una vez separemos los cables del conector, evitar que se toquen entre sí. Deberemos desconectar uno, aislarlo (con cinta aislante, por ejemplo), luego desconectar el otro y hacer lo mismo. Las capacidades de la entrada pueden haber quedado cargadas y podríamos provocar un cortocircuito.

El LVDT que mide el desplazamiento vertical debe estar aproximadamente en la mitad de desplazamiento al iniciar les medidas. Recordemos que el sistema recoge datos en DC, es decir, de 0 a xV positivos, si empezamos en la posición 0 y la muestra estira el núcleo hacia afuera nos devolverá valores negativos, los cuáles el sistema no leerá. Por tanto, el LVDT vertical, al ejecutar el comando de TEST, debe estar en aproximadamente en 6mm para poder medir desplazamiento tanto si se contrae el LVDT como si se estira. Podemos saber dónde se debe colocar simplemente pidiendo datos al sensor y ajustando manualmente el núcleo dentro del cuerpo del LVDT. Tenemos la opción de moverlo 6mm hacia los dos lados como máximo, pues el recorrido máximo que permite el transductor es de 12.5mm y si lo colocamos en 6mm para poder medir desplazamiento hacia los dos lados, tenemos 6mm para cada lado.

Cada vez que pidamos datos a un sensor en particular, se tomarán 5 datos. Si ejecutamos el programa completo, se tomarán un total de 10 datos por sensor, a excepción del LVDT horizontal, el feedback del actuador y la celda vertical, que nos devolverán únicamente 1 dato. Si ejecutamos el programa ‘TEST’ obtendremos un dato de cada sensor.

Para que las cámaras empiecen a tomar fotos deberemos enviarles un ‘trigger’. Podemos hacerlo accediendo al módulo ‘Cámaras’ en la aplicación y enviar el ‘trigger’ uno a uno o enviar el ‘trigger’ de las 4 cámaras a la vez.

Hemos de tener en cuenta que, si lo hacemos por separado, debemos hacerlo para todas las cámaras; si enviamos los ‘triggers’ de dos cámaras y probamos a enviar el ‘trigger’ conjunto, el sistema nos devolverá un error, pues estaríamos activando dos cámaras y parando las otras dos. El sistema tiene dos opciones: ir todas a una o cada una por su lado, pero no podemos hacer combinaciones.

Podremos sacar las tarjetas SD del módulo aun teniendo el sistema alimentado, siempre y cuando hayamos enviado el ‘trigger’ para parar de tomar imágenes; de no ser así, el Arduino intentaría seguir grabando imágenes en la SD y al no poder, corremos el riesgo de que se cuelgue, lo que nos obligaría a reiniciarlo.

Posibles fuentes de error
A continuación, se expone las posibles causas de un error en el sistema:
- Comando erróneo:
- Probabilidad: Muy baja.
- Significado: El usuario ha enviado un comando erróneo. El sistema sólo permite enviar unos comandos restringidos, es decir, los comandos posibles están limitados por la interfaz. Este error también puede ocurrir si falla la comunicación.
- Momento en el que puede ocurrir: Al enviar un comando.
- Solución: Revisar que el FTDI esté bien conectado a la PCB y enviar el comando de nuevo.
- ‘Trigger’ de las cámaras:
- Probabilidad: Baja.
- Significado: El usuario ha enviado un ‘trigger’ general en una situación en la cual no está permitido hacerlo.
- Momento en el que puede ocurrir: Al enviar un ‘trigger’ general a las cámaras.
- Solución: Revisar que todas las cámaras estén en el mismo estado (tomando fotos o paradas) y enviar los comandos para que así sea.
- Movimiento del actuador:
- Probabilidad: Media.
- Significado: Hemos intentado mover el actuador hacia adelante y ya está en su posición máxima o bien hemos intentado mover el actuador hacia atrás y ya está en su posición mínima.
También puede ocurrir si no hemos calibrado el sistema.
También puede ocurrir en una situación en la que intentemos mover el actuador y no esté conectado o bien el actuador o bien el LVDT.
- Momento en el que puede ocurrir: Al enviar un comando que implique mover el actuador.
- Solución: Revisar la posición del actuador y revisar el comando que queremos enviar. Revisar que hemos cogido un dato del LVDT del actuador y del ‘feedback’ del actuador antes de intentar mover la estructura. Revisar que el actuador y el LVDT estén bien conectados.
- Sobre corriente en el puente H:
- Probabilidad: Baja.
- Significado: Se ha producido un error por sobre corriente en el puente H.
- Momento en el que puede ocurrir: Al enviar un comando que implique mover el actuador.
- Solución: Revisar si hemos cruzado el positivo y el negativo de la fuente de 12V. Si no lo hemos hecho, puede haber algo roto o en mal estado en el puente H o en el circuito detector de sobre corriente.
- Arduino no encuentra la cámara o la SD:
- Probabilidad: Baja.
- Significado: El Arduino no ha encontrado la cámara o la tarjeta SD. Podría deberse a una mala conexión o que la alimentación del módulo sea incorrecta.
- Momento en el que puede ocurrir: Al conectar la alimentación a las cámaras.
- Solución: Revisar que todo esté bien conectado y reiniciar el Arduino pulsando el botón que se encuentra en el centro del dispositivo. Si no es el problema, debemos revisar que en la salida del DC/DC que alimenta el módulo tengamos 5V.

Posibles errores en el sistema sin aviso de los LEDs

Este apartado tiene el objetivo de describir posibles errores del sistema sin que salte el aviso de error mediante los LEDs. Estos pueden ser causados por algún componente roto, algún fallo en las conexiones o un desajuste en las tensiones de alimentación.

- Fallo en el movimiento del motor:
- Probabilidad: Baja.
- Situación: Hemos intentado mover el actuador, pero no se mueve. No hay error ni de comando erróneo ni de sobrecorriente en el puente H; el sistema parece colgado.
- Momento en el que puede ocurrir: Al intentar mover el actuador.
Solución: Una posibilidad es que el actuador no tenga suficiente velocidad para moverse; deberemos aumentarla e intentar de nuevo el movimiento.
Otra opción es que haya un desajuste en la tensión de alimentación. Revisar con un multímetro, directamente en los bornes de la fuente de 12V, que esté proporcionando 13.1V. Si no es así, deberemos ajustar la posición del potenciómetro (la rueda blanca situada al lado del conector de la fuente) hasta que veamos esa tensión. Si no proporcionamos correctamente la alimentación, puede saltar la protección de sub voltaje de los drivers del puente, que es una protección del propio componente.
- Fallo de comunicación entre el PC y la PCB:
- Probabilidad: Baja.
- Situación: Hemos intentado enviar un comando al PCB, pero no responde y no salta ningún error. El sistema parece colgado.
- Momento en el que puede ocurrir: Al enviar cualquier comando al PCB.
- Solución: Es probable que haya un error de conexión de los cables del FTDI al PCB. Debemos revisar la página 7 y mirar si hemos realizado correctamente la conexión.
- Fallo en la lectura de algún sensor:
- Probabilidad: Baja.
- Situación: Los valores que leemos en el documento de texto no parecen correctos.
- Momento en el que puede ocurrir: Al leer datos de algún sensor.
- Solución: Podemos haber conectado mal los cables del sensor a la PCB. Deberemos desconectar la alimentación inmediatamente y revisar que esté todo bien conectado. Es muy crítico el fallo si nos hemos equivocado al conectar la alimentación; deberemos revisar tanto la PCB como el sensor, que estén en buen estado. Si nos hemos equivocado en los cables de datos es probable que no haya pasado nada grave, probaremos a conectarlo bien y volveremos a pedir una medida.
Si no es problema de las conexiones puede deberse a un cambio en el setup final con respecto a las pruebas y por tanto que deba actualizarse el código. Podría ser tan sencillo como aumentar un poco el ‘timeout’ en el código de la aplicación, es decir, pedir al PC que espere algo más de tiempo a recibir datos desde la PCB; quizás los cables desde el PCB al ordenador son muy largos.

Enviar comandos desde la interfaz
Lo primero que deberemos hacer es conectar el FTDI al conector del PCB tal como se ha indicado anteriormente y conectarlo al ordenador. Ejecutaremos el archivo ‘HydroPore.exe’ para poder iniciar la aplicación. Es muy importante tener ese archivo en una ruta parecida a la siguiente: C:\Users\arnau\HydroPore. Si no lo tenemos localizado dentro del disco C y nuestro usuario, el programa no podrá generar el archivo donde guardará los datos recogidos.

Al iniciar la aplicación, se nos pide que seleccionemos el puerto en que hemos conectado el FTDI. Para saberlo, debemos ir al buscador de Windows y teclear ‘Administrador de dispositivos’, nos aparecerá la siguiente ventana:

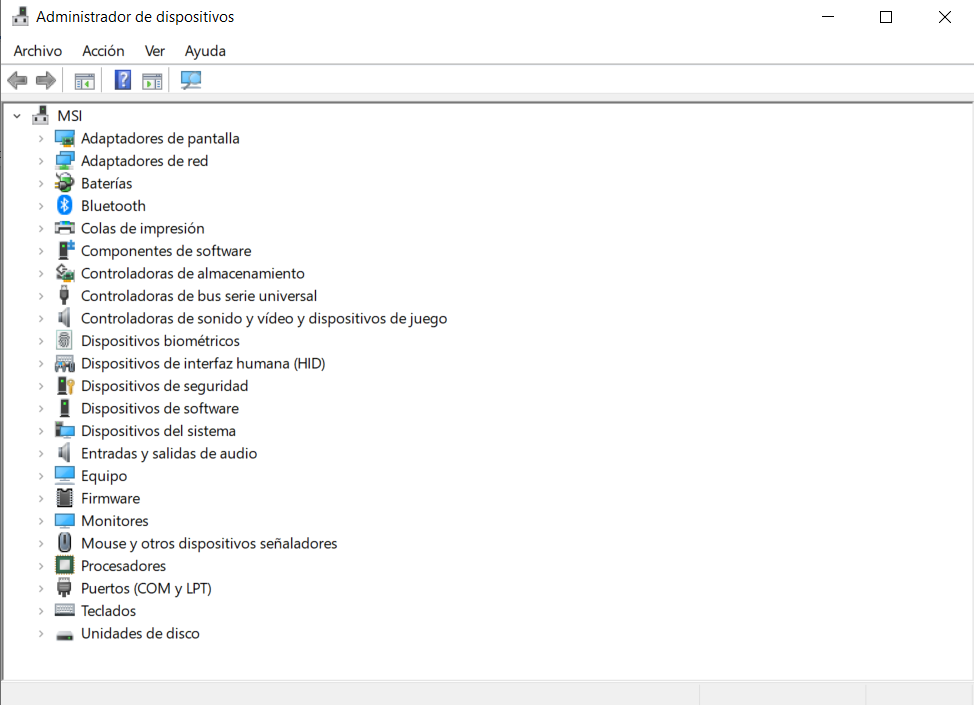
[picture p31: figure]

Desplegaremos la línea etiquetada como ‘Puertos (COM y LPT)’ y miraremos que puerto se ha asignado al dispositivo:

El valor entre paréntesis de la anterior imagen es el que deberemos indicar en la ventana principal de la interfaz:

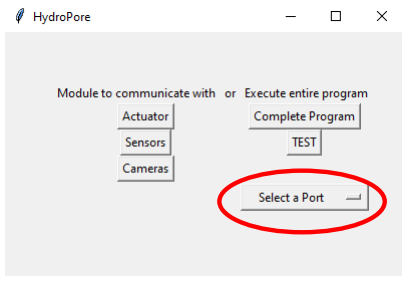
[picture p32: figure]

Una vez hecho, estaremos listos para enviar comandos al PCB.

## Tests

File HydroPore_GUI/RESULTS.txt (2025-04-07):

Sensor;LVDT_Actuator;Time;18:08:51;Data;3.047;mm
Sensor;LVDT_Vertical;Time;18:08:51;Data;0.015;mm
Sensor;Water;Time;18:08:51;Data;0.01221;bar
Sensor;Feedback;Time;18:08:51;Data;0.073;mm
Sensor;Load_Actuator;Time;18:08:51;Data;312.462;N
Sensor;Load_Death_Weight;Time;18:08:51;Data;312.462;N
Sensor;LVDT_Actuator;Time;18:10:18;Data;0.015;mm
Sensor;LVDT_Vertical;Time;18:10:18;Data;0.011;mm
Sensor;Water;Time;18:10:18;Data;0.01221;bar
Sensor;Feedback;Time;18:10:18;Data;0.11;mm
Sensor;Load_Actuator;Time;18:10:18;Data;312.462;N
Sensor;Load_Death_Weight;Time;18:10:18;Data;312.462;N
Sensor;LVDT_Actuator;Time;18:12:42;Data;0.015;mm
Sensor;LVDT_Vertical;Time;18:12:42;Data;0.011;mm
Sensor;Water;Time;18:12:42;Data;0.01221;bar
Sensor;Feedback;Time;18:12:42;Data;9.473;mm
Sensor;Load_Actuator;Time;18:12:42;Data;312.462;N
Sensor;Load_Death_Weight;Time;18:12:42;Data;312.462;N
Sensor;LVDT_Actuator;Time;18:13:13;Data;0.019;mm
Sensor;LVDT_Vertical;Time;18:13:13;Data;0.011;mm
Sensor;Water;Time;18:13:13;Data;0.01221;bar
Sensor;Feedback;Time;18:13:13;Data;0.11;mm
Sensor;Load_Actuator;Time;18:13:13;Data;312.462;N
Sensor;Load_Death_Weight;Time;18:13:13;Data;312.462;N
Sensor;LVDT_Actuator;Time;18:13:57;Data;0.015;mm
Sensor;LVDT_Vertical;Time;18:13:57;Data;0.015;mm
Sensor;Water;Time;18:13:57;Data;0.00977;bar
Sensor;Feedback;Time;18:13:57;Data;9.534;mm
Sensor;Load_Actuator;Time;18:13:57;Data;312.462;N
Sensor;Load_Death_Weight;Time;18:13:57;Data;312.462;N
Sensor;LVDT_Actuator;Time;18:14:10;Data;0.015;mm
Sensor;LVDT_Vertical;Time;18:14:10;Data;0.015;mm
Sensor;Water;Time;18:14:10;Data;0.01221;bar
Sensor;Feedback;Time;18:14:10;Data;0.085;mm
Sensor;Load_Actuator;Time;18:14:10;Data;312.462;N
Sensor;Load_Death_Weight;Time;18:14:10;Data;312.462;N
Sensor;LVDT_Actuator;Time;18:18:14;Data;0.127;mm
Sensor;LVDT_Vertical;Time;18:18:14;Data;0.015;mm
Sensor;Water;Time;18:18:14;Data;0.01221;bar
Sensor;Feedback;Time;18:18:14;Data;0.073;mm
Sensor;Load_Actuator;Time;18:18:14;Data;312.462;N
Sensor;Load_Death_Weight;Time;18:18:14;Data;312.462;N
Sensor;LVDT_Actuator;Time;18:19:40;Data;0.127;mm
Sensor;LVDT_Vertical;Time;18:19:40;Data;0.015;mm
Sensor;Water;Time;18:19:40;Data;0.01221;bar
Sensor;Feedback;Time;18:19:40;Data;0.208;mm
Sensor;Load_Actuator;Time;18:19:40;Data;312.462;N
Sensor;Load_Death_Weight;Time;18:19:40;Data;312.462;N
Sensor;LVDT_Actuator;Time;18:19:46;Data;2.091;mm
Sensor;LVDT_Vertical;Time;18:19:46;Data;0.011;mm
Sensor;LVDT_Vertical;Time;18:19:46;Data;0.011;mm
Sensor;LVDT_Vertical;Time;18:19:46;Data;0.015;mm
Sensor;LVDT_Vertical;Time;18:19:46;Data;0.015;mm
Sensor;LVDT_Vertical;Time;18:19:46;Data;0.015;mm
Sensor;LVDT_Vertical;Time;18:19:46;Data;0.015;mm
Sensor;LVDT_Vertical;Time;18:19:46;Data;0.015;mm
Sensor;LVDT_Vertical;Time;18:19:46;Data;0.015;mm
Sensor;LVDT_Vertical;Time;18:19:46;Data;0.015;mm
Sensor;LVDT_Vertical;Time;18:19:46;Data;0.015;mm
Sensor;Water;Time;18:19:46;Data;0.01221;bar
Sensor;Water;Time;18:19:46;Data;0.01221;bar
Sensor;Water;Time;18:19:46;Data;0.01221;bar
Sensor;Water;Time;18:19:46;Data;0.01221;bar
Sensor;Water;Time;18:19:46;Data;0.01221;bar
Sensor;Water;Time;18:19:46;Data;0.01221;bar
Sensor;Water;Time;18:19:46;Data;0.01221;bar
Sensor;Water;Time;18:19:46;Data;0.01221;bar
Sensor;Water;Time;18:19:46;Data;0.01221;bar
Sensor;Water;Time;18:19:46;Data;0.01221;bar
Sensor;Feedback;Time;18:19:46;Data;2.002;mm
Sensor;Load_Actuator;Time;18:19:46;Data;312.462;N
Sensor;Load_Actuator;Time;18:19:46;Data;312.462;N
Sensor;Load_Actuator;Time;18:19:46;Data;312.462;N
Sensor;Load_Actuator;Time;18:19:46;Data;312.462;N
Sensor;Load_Actuator;Time;18:19:46;Data;312.462;N
Sensor;Load_Actuator;Time;18:19:46;Data;312.462;N
Sensor;Load_Actuator;Time;18:19:46;Data;312.462;N
Sensor;Load_Actuator;Time;18:19:46;Data;312.462;N
Sensor;Load_Actuator;Time;18:19:46;Data;312.462;N
Sensor;Load_Actuator;Time;18:19:46;Data;312.462;N
Sensor;Load_DeathWeigth;Time;18:19:46;Data;312.462;N
Sensor;LVDT_Actuator;Time;18:19:49;Data;3.065;mm
Sensor;LVDT_Vertical;Time;18:19:49;Data;0.011;mm
Sensor;LVDT_Vertical;Time;18:19:49;Data;0.015;mm
Sensor;LVDT_Vertical;Time;18:19:49;Data;0.015;mm
Sensor;LVDT_Vertical;Time;18:19:49;Data;0.015;mm
Sensor;LVDT_Vertical;Time;18:19:49;Data;0.015;mm
Sensor;LVDT_Vertical;Time;18:19:49;Data;0.011;mm
Sensor;LVDT_Vertical;Time;18:19:49;Data;0.015;mm
Sensor;LVDT_Vertical;Time;18:19:49;Data;0.015;mm
Sensor;LVDT_Vertical;Time;18:19:49;Data;0.015;mm
Sensor;LVDT_Vertical;Time;18:19:49;Data;0.015;mm
Sensor;Water;Time;18:19:49;Data;0.01221;bar
Sensor;Water;Time;18:19:49;Data;0.01221;bar
Sensor;Water;Time;18:19:49;Data;0.01221;bar
Sensor;Water;Time;18:19:49;Data;0.01465;bar
Sensor;Water;Time;18:19:49;Data;0.01221;bar
Sensor;Water;Time;18:19:49;Data;0.01221;bar
Sensor;Water;Time;18:19:49;Data;0.01221;bar
Sensor;Water;Time;18:19:49;Data;0.01221;bar
Sensor;Water;Time;18:19:49;Data;0.01221;bar
Sensor;Water;Time;18:19:49;Data;0.01221;bar
Sensor;Feedback;Time;18:19:49;Data;2.832;mm
Sensor;Load_Actuator;Time;18:19:49;Data;312.462;N
Sensor;Load_Actuator;Time;18:19:49;Data;312.462;N
Sensor;Load_Actuator;Time;18:19:49;Data;312.462;N
Sensor;Load_Actuator;Time;18:19:49;Data;312.462;N
Sensor;Load_Actuator;Time;18:19:49;Data;312.462;N
Sensor;Load_Actuator;Time;18:19:49;Data;312.462;N
Sensor;Load_Actuator;Time;18:19:49;Data;312.462;N
Sensor;Load_Actuator;Time;18:19:49;Data;312.462;N
Sensor;Load_Actuator;Time;18:19:49;Data;312.462;N
Sensor;Load_Actuator;Time;18:19:49;Data;312.462;N
Sensor;Load_DeathWeigth;Time;18:19:49;Data;312.462;N

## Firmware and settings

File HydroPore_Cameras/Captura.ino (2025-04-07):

// This is a basic snapshot sketch using the VC0706 library.
// On start, the Arduino will find the camera and SD card and
// then snap a photo, saving it to the SD card.
// Public domain.

// If using an Arduino Mega (1280, 2560 or ADK) in conjunction
// with an SD card shield designed for conventional Arduinos
// (Uno, etc.), it's necessary to edit the library file:
//   libraries/SD/utility/Sd2Card.h
// Look for this line:
//   #define MEGA_SOFT_SPI 0
// change to:
//   #define MEGA_SOFT_SPI 1
// This is NOT required if using an SD card breakout interfaced
// directly to the SPI bus of the Mega (pins 50-53), or if using
// a non-Mega, Uno-style board.

#include <Adafruit_VC0706.h>
#include <SPI.h>
#include <SD.h>

// comment out this line if using Arduino V23 or earlier
#include <SoftwareSerial.h>         

// uncomment this line if using Arduino V23 or earlier
// #include <NewSoftSerial.h>       

// SD card chip select line varies among boards/shields:
// Adafruit SD shields and modules: pin 10
// Arduino Ethernet shield: pin 4
// Sparkfun SD shield: pin 8
// Arduino Mega w/hardware SPI: pin 53
// Teensy 2.0: pin 0
// Teensy++ 2.0: pin 20
#define chipSelect 10

// Pins for camera connection are configurable.
// With the Arduino Uno, etc., most pins can be used, except for
// those already in use for the SD card (10 through 13 plus
// chipSelect, if other than pin 10).
// With the Arduino Mega, the choices are a bit more involved:
// 1) You can still use SoftwareSerial and connect the camera to
//    a variety of pins...BUT the selection is limited.  The TX
//    pin from the camera (RX on the Arduino, and the first
//    argument to SoftwareSerial()) MUST be one of: 62, 63, 64,
//    65, 66, 67, 68, or 69.  If MEGA_SOFT_SPI is set (and using
//    a conventional Arduino SD shield), pins 50, 51, 52 and 53
//    are also available.  The RX pin from the camera (TX on
//    Arduino, second argument to SoftwareSerial()) can be any
//    pin, again excepting those used by the SD card.
// 2) You can use any of the additional three hardware UARTs on
//    the Mega board (labeled as RX1/TX1, RX2/TX2, RX3,TX3),
//    but must specifically use the two pins defined by that
//    UART; they are not configurable.  In this case, pass the
//    desired Serial object (rather than a SoftwareSerial
//    object) to the VC0706 constructor.

// Using SoftwareSerial (Arduino 1.0+) or NewSoftSerial (Arduino 0023 & prior):
#if ARDUINO >= 100
// On Uno: camera TX connected to pin 2, camera RX to pin 3:
SoftwareSerial cameraconnection = SoftwareSerial(2, 3);
// On Mega: camera TX connected to pin 69 (A15), camera RX to pin 3:
//SoftwareSerial cameraconnection = SoftwareSerial(69, 3);
#else
NewSoftSerial cameraconnection = NewSoftSerial(2, 3);
#endif

Adafruit_VC0706 cam = Adafruit_VC0706(&cameraconnection);

// Using hardware serial on Mega: camera TX conn. to RX1,
// camera RX to TX1, no SoftwareSerial object is required:
//Adafruit_VC0706 cam = Adafruit_VC0706(&Serial1);

char Trigger = 0; //If = 1, the Arduino should be taking photos.
int32_t Photo = 0;

void setup() {

  // When using hardware SPI, the SS pin MUST be set to an
  // output (even if not connected or used).  If left as a
  // floating input w/SPI on, this can cause lockuppage.
#if !defined(SOFTWARE_SPI)
#if defined(__AVR_ATmega1280__) || defined(__AVR_ATmega2560__)
  if(chipSelect != 53) pinMode(53, OUTPUT); // SS on Mega
#else
  if(chipSelect != 10) pinMode(10, OUTPUT); // SS on Uno, etc.
#endif
#endif

  pinMode(10, OUTPUT);
  pinMode(A1, OUTPUT); // Use thin pin as a advice LED of and incorrect setup
  digitalWrite(A1, LOW);
  pinMode(A5, OUTPUT); // Use thin pin as a advice LED of an correct ejecution of program
  digitalWrite(A5, LOW);
  pinMode(6,OUTPUT); //RST pin of the 555, to put the out of 555 to 0 when we receive a trigger from the principal uC
  digitalWrite(6, LOW);
  pinMode(5, INPUT);  //Output from the 555, when we receive first trigger we want to take photos. When we receive the second trigger, we want to stop taking photos. 
  Serial.begin(115200);
  Serial.println("VC0706 Camera snapshot test");
  
  // see if the card is present and can be initialized:
  if (!SD.begin(chipSelect)) {
    Serial.println("Card failed, or not present");
    // don't do anything more:
    while(1){
      digitalWrite(A5, HIGH);
      delay(2000);
      digitalWrite(A5, LOW);
      delay(2000);
    }
  }  
  
  // Try to locate the camera
  if (cam.begin()) {
    Serial.println("Camera Found:");
  } else {
    Serial.println("No camera found?");
    while(1){
      digitalWrite(A5, HIGH);
      delay(2000);
      digitalWrite(A5, LOW);
      delay(2000);
    }
  }
  // Print out the camera version information (optional)
  /*char *reply = cam.getVersion();
  if (reply == 0) {
    Serial.print("Failed to get version");
  } else {
    Serial.println("-----------------");
    Serial.print(reply);
    Serial.println("-----------------");
  }*/

  // Set the picture size - you can choose one of 640x480, 320x240 or 160x120 
  // Remember that bigger pictures take longer to transmit!
  
  cam.setImageSize(VC0706_640x480);        // biggest
  //cam.setImageSize(VC0706_320x240);        // medium
  //cam.setImageSize(VC0706_160x120);          // small

  // You can read the size back from the camera (optional, but maybe useful?)
  uint8_t imgsize = cam.getImageSize();
  Serial.print("Image size: ");
  if (imgsize == VC0706_640x480) Serial.println("640x480");
  if (imgsize == VC0706_320x240) Serial.println("320x240");
  if (imgsize == VC0706_160x120) Serial.println("160x120");
}

void loop() {
  //Serial.println("Snap in 5 secs...");
  //delay(5000);

  if(digitalRead(5) == HIGH){ //If we read 1 at the OUT of 555, UC has sent a trigger
    Trigger ^= 1;
    digitalWrite(6, HIGH); //Activate Reset to wait for another trigger
    delay(500);
    digitalWrite(6, LOW); 
  }
  while(Trigger == 0){ //Wait until the uC tell us to take photos
    digitalWrite(A1, HIGH);
    if(digitalRead(5) == HIGH){
      delay(1000); //To wait for the 'set' pin go low
      digitalWrite(6, HIGH);
      delay(500);
      digitalWrite(6, LOW); 
      Trigger ^= 1;
    }
  }  

  digitalWrite(A5, HIGH); //Red led ON and green off to advice that the system is busy
  digitalWrite(A1, LOW);
  
  if (! cam.takePicture()) 
    Serial.println("Failed to snap!");
  else 
    Serial.println("Picture taken!");
  
  // Create an image with the name IMAGExx.JPG
  char filename[13];
  strcpy(filename, "IMAGE00.JPG");
  for (int i = 0; i < 100; i++) {
    filename[5] = '0' + i/10;
    filename[6] = '0' + i%10;
    // create if does not exist, do not open existing, write, sync after write
    if (! SD.exists(filename)) {
      break;
    }
  }
  
  // Open the file for writing
  File imgFile = SD.open(filename, FILE_WRITE);

  // Get the size of the image (frame) taken  
  uint16_t jpglen = cam.frameLength();
  Serial.print("Storing ");
  Serial.print(jpglen, DEC);
  Serial.print(" byte image.");

  int32_t time = millis();
  pinMode(8, OUTPUT);
  // Read all the data up to # bytes!
  byte wCount = 0; // For counting # of writes
  while (jpglen > 0) {
    // read 32 bytes at a time;
    uint8_t *buffer;
    uint8_t bytesToRead = min(32, jpglen); // change 32 to 64 for a speedup but may not work with all setups!
    buffer = cam.readPicture(bytesToRead);
    imgFile.write(buffer, bytesToRead);
    if(++wCount >= 64) { // Every 2K, give a little feedback so it doesn't appear locked up
      Serial.print('.');
      wCount = 0;
    }
    //Serial.print("Read ");  Serial.print(bytesToRead, DEC); Serial.println(" bytes");
    jpglen -= bytesToRead;
  }
  imgFile.close();

  File myFile = SD.open("Time.txt", FILE_WRITE);
  if(myFile)
  {
    myFile.println();
    myFile.print("Photo ");
    myFile.print(Photo);
    myFile.print(": ");
    myFile.print(time);
    myFile.print("ms elapsed since start");
    myFile.close();
    Photo = Photo + 1; 
  }
  else{
    Serial.println("Error opening the .txt");
  }

  time = millis() - time;
  Serial.println("done!");
  digitalWrite(A5, LOW);
  digitalWrite(A1, HIGH);
  delay(1000);
  Serial.print(time); Serial.println(" ms elapsed");
}

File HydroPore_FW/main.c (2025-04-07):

/*
 * Project: HydroPore
 *
 * This project is realized by Arnau Quintana, for the University of Barcelona.
 * Its distribution is totally prohibited without permission of its author or the project members.
 */
#include <msp430.h>
#include <stdint.h>
#include <stdio.h>

#include "ADC.h"
#include "COMs.h"
#include "Clocks.h"
#include "DrivingH.h"
#include "Control.h"

int main(void)
{

    WDTCTL = WDTPW | WDTHOLD;	// stop watchdog timer

	__disable_interrupt();

	/*GPIOs that will control activation of the external ADCs*/
    P4DIR |= BIT6 + BIT5; //Bit 5 for the load cell 2 and bit for the load cell 1
    P4OUT |= BIT6 + BIT5; //High state will maintain ADC in shutdown

    /*We use the I2C pins as GPIOs for indicator LEDs*/
    P3DIR |= BIT6 + BIT7;
    P3OUT |= BIT6;
    P3OUT &= ~BIT7;

	init_clocks(); //Initialize clock module
	init_GPIOs_Cams();//Initialize GPIOs that control cameras
	init_UART_COM(); //Initialize module in UART mode in order to receive commands
	init_timer_US(); //Initialize timer that controls the ultrasonic sensor
	init_timers_GPIO_HBridge(); //Initialize all PWM and GPIos that control the H bridge
	init_ADC(); //Initialize ADC

	__enable_interrupt();

	RxStruct UART_DATA; //Struct where we will save data received

	while(1)
	{
	    P3OUT |= BIT6; //Green LED ON to indicate that the system is waiting for a command
	    P3OUT &= ~BIT7; //Red Led OFF to indicate that the system is waiting for a command and no errors has been produced

	    UART_DATA = receive_DataUART_COM(5); //Wait for data from UART with a timeout of 10ms
	    if(UART_DATA.Packet[0] == 'A' || UART_DATA.Packet[0] == 'S' || UART_DATA.Packet[0] == 'C' || UART_DATA.Packet[0] == 'P'
	       || UART_DATA.Packet[0] == 'T') //Only if we receive permitted commands, we will execute the principal function
	    {
	       Analyze_received_data(UART_DATA.Packet);
	    }
        __delay_cycles(1600); //To introduce a little delay of 10ms between checking the port
	}
}

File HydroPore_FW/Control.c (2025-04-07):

/*
 * Control.c
 *
 *  Created on: 07 may 2022
 *      Author: Arnau Quintana
 *
 * This file contains the functions related with control of the system
 */

#include <msp430.h>
#include <stdint.h>
#include <stdio.h>

#include "COMs.h"
#include "DrivingH.h"
#include "ADC.h"
#include "Control.h"

struct System_Data Last_system_data; //Will save last adc results
struct System_Data Actual_system_data = {0,0,0,0,0}; //Will save actual adc results
uint8_t First_LVDT1_Data = 1;  //Variable that avoids movement of the actuator if the user hasn't take a LVDT1 measurement
uint8_t First_Feedback_Data = 1; //Variable that avoids movement of the actuator if the user hasn't take a feedback measurement

uint8_t Data_to_Send[2]; //Variable to save data that we will send to PC

uint16_t Feedback_Data[64];
uint16_t LVDT1_Data[64];
uint16_t Load_Data[64];
uint16_t LVDT2_Data[64];
uint16_t Water_Data[64]; //Array where data measures from the Pressure Sensor will be saved

uint8_t object_detected = 0; //If = 1, US sensor has detected an object
uint8_t i; //Variable for loops

/*
 * This function will execute a complete routine of the system
 */
void Complete_Program()
{
    uint8_t P = 0; //Variable to indicate the array position where the data will be saved
    uint8_t L = 0; //Variable to know how many data from the LVDT1 we have
    uint8_t Steady_state_Water = 0;//To count how many times the Water Pressure sensor measures the same value
    uint16_t Timeout = 0; //To avoid an infinite loop if the actuator or LVDT are not connected

    object_detected = US_value();//We take data from the US sensor to know if the actuator is in maximum position
    Actual_system_data.Feedback = measure_feedbackActuator(); //We take data from the feedback to ensure that we can go forward
    __delay_cycles(16000);
    Actual_system_data.LVDT1 = measure_LVDT1(); //We get data from the LVDT
    if(!object_detected && Actual_system_data.Feedback < 800 && Actual_system_data.LVDT1 < 3200 && !First_LVDT1_Data /*&& Actual_system_data.LVDT1 > 5*/) //Actuator isn't in maximum position, and we already taken the first
    {                                                                       //LVDT1 data, we can move 1mm forward
        Actuator_Move(FORWARD, 0); //Move the actuator forward
        while((Actual_system_data.LVDT1 < Last_system_data.LVDT1 + 260) && ((P3IN & BIT5) == BIT5)) //While LVDT data doesn't change, the actuator hasn't arrived yet.
        {                                                                                           //Or and OC situation has been produced
            Actual_system_data.LVDT1 = measure_LVDT1(); //We get data from the LVDT
            __delay_cycles(1600);//Little delay between ADC conversions (x[s]/MCLK)
            L++;
            if(Actual_system_data.LVDT1 <= Last_system_data.LVDT1 + 5) //If the measurement of the LVDT doesn't change
            {                                                          //We will suppose that the actuator or the LVDT
                Timeout++;                                             //are not connected
                if(Timeout == 35000) break;
            }
            if(L == 50 && P < 10) //Will take 10 measures from the CELL1, the Pressure Sensor and the LVDT2
            {
                Water_Data[P]= measure_WaterSensor();
                __delay_cycles(1600);//Little delay between ADC conversions (x[s]/MCLK)
                Load_Data[P] = SPI_Data_LoadCell(1); //Get data from the Load Cell 1
                __delay_cycles(1600);//Little delay between ADC conversions (x[s]/MCLK)
                LVDT2_Data[P] = measure_LVDT2(); //We get data from the LVDT2
                L = 0;
                P++;

                init_UART_COM(); //We need to reconfigure the module in order to use it in UART mode
                Data_to_Send[0] = 'T';
                send_DATAUART_COM(1, Data_to_Send); //Send a trigger to PC to make a timestamp
            }
        }
        Actuator_Move(STOP, 0); //Actuator has arrived to the new position

        Actual_system_data.Load2 = SPI_Data_LoadCell(2); //Get data from the Load Cell 2

        init_UART_COM();
        Data_to_Send[0] = 'S';
        send_DATAUART_COM(1, Data_to_Send); //Send a stop command to PC to let it know when it has to stop waiting for trigger

        if(Actual_system_data.LVDT1 < Last_system_data.LVDT1 + 260) //If we left the last while without a change on LVDT data
        {                                                           //OC has produced, we need to advice the user
            if(Timeout != 35000) //We stopped the movement because of an OC situation
            {
                for(i = 0; i < 20; i++)
                {
                    P3OUT ^= BIT6; //Two leds with toggle 20 times to advice the user there's some error in circuit
                    P3OUT ^= BIT7;
                    __delay_cycles(1600000);
                }
            }
            else //The measures are the same for a long time, the LVDT or the actuator aren't connected
            {
                for(i = 0; i < 20; i++)
                {
                    P3OUT |= BIT6; //Green Led ON and Red blinking to indicate that actuator won't move
                    P3OUT ^= BIT7;
                    __delay_cycles(1600000);
                }
            }
        }

         while(Steady_state_Water < 15) //We have to check when the system is in the steady state
         {
             Last_system_data.Water = Actual_system_data.Water;
             Actual_system_data.Water = measure_WaterSensor();
             if(Actual_system_data.Water > 5) //Measures must be greater than 5, if are not, we suppose that thse sensor is not connected
             {
                 if(Actual_system_data.Water < Last_system_data.Water + 50 && Actual_system_data.Water > Last_system_data.Water - 50)
                 {
                     Steady_state_Water += 1;
                 }
             __delay_cycles(16000); //1ms between measures
             }
             else{break;} //Sensor is not connected, we avoid an infinite loop just skipping this part
         }

         init_UART_COM();
         Data_to_Send[0] = 'R'; //We send 'Ready' command to let the PC know when we are going to start sending data
         send_DATAUART_COM(1, Data_to_Send);

         LVDT1_Data[0] = Actual_system_data.LVDT1;

         Data_to_Send[0] =  LVDT1_Data[0] >> 8;//Upper part of the 16 bit number
         Data_to_Send[1] =  LVDT1_Data[0] & 0xFF; //Lower part of the 16 bit number
         send_DATAUART_COM(2, Data_to_Send);

         for(i = 0; i < P; i++) //Send to the PC all data
         {
             Data_to_Send[0] =  LVDT2_Data[i] >> 8;//Upper part of the 16 bit number
             Data_to_Send[1] =  LVDT2_Data[i] & 0xFF; //Lower part of the 16 bit number
             send_DATAUART_COM(2, Data_to_Send);
         }
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

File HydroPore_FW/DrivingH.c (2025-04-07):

/*
 * DrivingH.c
 *
 *  Created on: 28 apr. 2022
 *      Author: Arnau Quintana
 *
 * This file contains the functions related with de H Bridge
 */

#include <msp430.h>
#include <stdint.h>
#include <stdio.h>
#include "DrivingH.h"
#include "ADC.h"

/*********************************ULTRASONIC SENSOR*****************************************/

uint16_t Value1_capture, Value2_capture, Capture_result;
float ReturnData;
uint8_t Captured_data;

/*
 * Function that will initialitzes the timer that control the US sensor
 */
void init_timer_US(void)
{
    TA4CTL |= MC_2 | TASSEL_2 | ID_3 | TACLR; //Mode Continuous. Timer CLK = SMCLK/8 = 2MHz. Clear.
    TA4EX0 |= TAIDEX_7; //Timer CLK = 2MHz / 8 = 250KHz -> Periodo de 4us.
    TA4CCTL1 |= CM_3 | CCIS_0 | SCS | CAP | CCIE;
    /* Capture in the two edges
     * Input CCI1A (P5.5, TA4.1)
     * Synchronous Capture
     * Capture Mode
     * Interruption ON
     */
    TA4CCTL1 &= ~CCIFG; //To ensure correct operation, clear the interruption flag

    P5DIR |= BIT3;  //GPIO that will trigger the sensor
    P5SEL0 |= BIT5; //Alternative function for the pin that will capture the values from the US sensor

    P5OUT &= ~BIT3;
}

/*
 * Function that will control de US sensor
 */
uint8_t US_value(void)
{
    uint8_t Timeout = 0;

    Captured_data = 0; //Will capture 2 values, rising edge and falling edge
    Value1_capture = 0;  //Value captured in rising edge
    Value2_capture = 0; //Value captures in falling edge

    P5OUT |= BIT3;  //Trigger the pulse to get data from the sensor
    __delay_cycles(16000); //MCLK = 16MHz. So 16000 will give a 1ms delay
    P5OUT &= ~BIT3;
    TA4CTL |= TACLR; //Reset el TB3R register

    while(Captured_data < 2) //We need 2 values from the US, so we will wait here until the interrupt shoots two times
    {
        Timeout++;
        if(Timeout > 250)
        {
            Timeout = 250;
            break;
        }
    }

    Capture_result = Value2_capture - Value1_capture; //Clock pulses between the two captured values

    ReturnData = Capture_result * (4e-3); //Period de 4us, yet we want the result in ms, that's why e-3 and no e-6.

    if(Timeout == 250) //Ultrasonic sensor is not connected
    {                  //Is an extra protection so we can use the system without it
        return 0;      //We return a 0 to avoid a infinite loop waiting for data
    }
    else
    {
        if (ReturnData < 0.400) //Range of pulse between 100us-18ms, in this case >5ms.
        {
            return 1; //object detected
        }
        else
        {
            return 0; //No object detected
        }
    }
}

/*
 * Interrupt routine of the timer that control US sensor
 */

#pragma vector = TIMER4_A1_VECTOR
__interrupt void Timer4_A1_ISR (void)
{
    TA4CCTL1 &= ~CCIFG;
    if(Captured_data == 0) Value1_capture = TA4CCR1; //First interrupt will occur with a rising edge
    else Value2_capture = TA4CCR1; //Second interrupt will occuren in a falling edge
    Captured_data++;
}

/******************************ACTUATOR******************************************/

/*
 * Timers to generate the two PWM signals of the high side transistors
 */
void init_timers_GPIO_HBridge(void)
{
    //GPIO for the OV signal
    P3DIR &= ~BIT5; //Pin to read the digital value from the OV circuit
    P3REN |= BIT5; //Enable pullup/pulldown resistor
    P3OUT &= ~BIT5; //Pulldown. In normal working, OV circuit will return 1.

    //GPIO pins for the low-side transitors
    P6DIR |= BIT7 + BIT3; //P6.3 -> transistor D. P6.7 -> transistor B
    P6OUT &= 0x00; //To ensure that initially they remain off

    //PWM pins for the high-side transistors
    P3DIR |= BIT2 + BIT3; //Pins as outputs
    P3SEL1 &= ~BIT2;  //Function of the pins PWM Transistor A
    P3SEL0 |= BIT2;
    P3SEL0 &= ~BIT3;  //Function of the pins PWM Transistor C
    P3SEL1 |= BIT3;

    //PWM for the A transistor in the scheme (Timer A1 block 1)
    TA1CCTL1 = OUTMOD_0; //We start with Mode 0, but we need mode 7 to generate PWM signal
    TA1CCR0 = 1000 - 1; //PWM frequency = 1kHz
    TA1CCR1 = 110; //110 equal to 11% of duty cycle, we can change this value during the program
    TA1CTL = TASSEL_2 + MC_1 + ID_3 + TACLR;//SMCLK, Count Up, ID = /8 (16MHz->8MHz), Clear TA0R register
    TA1EX0 = TAIDEX_1;//8Mhz/2 -> 4Mhz

    //PWM for the C transistor in the scheme (Timer B0 block 3)
    TB0CCTL3 = OUTMOD_0; //We start with Mode 0, but we need mode 7 to generate PWM signal
    TB0CCR0 = 1000 - 1; //PWM frequency = 1kHz
    TB0CCR3 = 110; //110 equal to 11% of duty cycle, we can change this value during the program
    TB0CTL = TBSSEL_2 + MC_1 + ID_3 + TBCLR;//SMCLK, Count Up, ID = /1, Clear TB0R register
    TB0EX0 = TAIDEX_1; //8Mhz/2 -> 4Mhz
}

/*
 * Function that will decide the movement of the actuator
 */
void Actuator_Move(char Direction, char Speed)
{
    switch(Direction)
    {
    case FORWARD:
        TA1CCTL1 = OUTMOD_7; //Enable transistor A
        TB0CCTL3 = OUTMOD_0; //Disable transistor C
        P6OUT |= 0x08; //P6.3 to activate transistor D
        break;
    case BACK:
        TA1CCTL1 = OUTMOD_0; //Disable transistor A
        TB0CCTL3 = OUTMOD_7; //Enable transistor C
        P6OUT |= 0x80; //P6.7 to activate transistor B
        break;
    case STOP:
        TA1CCTL1 = OUTMOD_0; //Disable two high side transistors
        TB0CCTL3 = OUTMOD_0;
        P6OUT &= 0x77; //Disable two low side transistors
        break;
    }

    switch(Speed)
    {
    case FAST:
        if(TA1CCR1 < 191) //If it is slower than 19%, we can increase the duty cycle up to 20%
        {
            TA1CCR1 += 10;
            TB0CCR3 += 10;
        }
        else //If we enter to this condition, will mean that we are working at 20%, is the maximum duty cycle value permitted
        {
            TA1CCR1 = TA1CCR1;//We won't change the duty cycle
            TB0CCR3 = TB0CCR3;
        }
        break;
    case SLOW: //If we want to go slow
        if(TA1CCR1 > 119) //We will check if the duty is higher than 11%
        {
            TA1CCR1 -= 10; //We will decrease the duty cycle
            TB0CCR3 -= 10;
        }
        else //if is is lower than 11%, it means that we are working at 10% of duty, it is the slowest value permitted
        {
            TA1CCR1 = TA1CCR1; //We won't change the duty cycle
            TB0CCR3 = TB0CCR3;
        }
        break;
    default: //default case is to do anything
        TA1CCR1 = TA1CCR1; //We won't change the duty cycle
        TB0CCR3 = TB0CCR3;
        break;
    }
}

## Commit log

2025-04-08 Update and sort folders
    [MCU.SchDoc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]
2025-04-08 Changes in Cameras project
